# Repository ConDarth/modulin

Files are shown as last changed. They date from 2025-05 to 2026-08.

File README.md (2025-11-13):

# Modulin

This repository holds all data for th modulin I am building. The concept behind this design is to make a fully analog synthesizer using only standard components, with a fun control system based on a violin. This project is mostly based on a design Martin Molin of Wintergatan. An explanation of his design can be found [here](https://www.youtube.com/watch?v=MUdWeBYe3GY). 

My goal in improving this design is to make it more accessible. His design uses 9 or so prebuilt modules meant for modular synthesizers, each of which costs in the range of 70$+ making the instrument quite expensive for a diy build. I took inspiration from the modular synth DIY community to instead try and build the necessary modules from scratch using only much cheaper standard electronics components. The components I am limiting myself to are resistors, capacitors, inductors/transformers, diodes, transistors (both BJT and FET), op amps and linear voltage regulators.

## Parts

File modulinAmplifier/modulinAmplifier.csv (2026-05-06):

Reference | Qty | Value | DNP | Exclude from BOM | Exclude from Board | Footprint | Datasheet
C1,C2,C6 | 3 | 100u |  |  |  | User:C_Radial_Polarized_P3.8mm_CNC
C3,C4 | 2 | 1u |  |  |  | User:C_Axial_P5.00mm_CNC | ~
C5 | 1 | 10u |  |  |  | User:C_Axial_P5.00mm_CNC | ~
C7 | 1 | 33n |  |  |  | User:C_Axial_P5.00mm_CNC | ~
C8 | 1 | 47n |  |  |  | User:C_Axial_P5.00mm_CNC | ~
C9 | 1 | 220u |  |  |  | User:C_Radial_Polarized_P3.8mm_CNC
C10 | 1 | 100n |  |  |  | User:C_Axial_P5.00mm_CNC | ~
D1,D2 | 2 | 1N4148 |  |  |  | User:D_P7.62mm_CNC | https://assets.nexperia.com/documents/data-sheet/1N4148_1N4448.pdf
J1 | 1 | Screw_Terminal_01x04 |  |  |  | User:TerminalBlock_1x4_CNC | ~
J2 | 1 | AudioJack3_SwitchTR |  |  |  | Connector_Audio:Jack_3.5mm_CUI_SJ1-3525N_Horizontal | ~
J3 | 1 | Screw_Terminal_01x02 |  |  |  | User:TerminalBlock_1x2_CNC | ~
R1 | 1 | 1M |  |  |  | User:R_10.16mm_CNC | ~
R2 | 1 | 100 |  |  |  | User:R_10.16mm_CNC | ~
R3 | 1 | 10k |  |  |  | User:R_7.62mm_CNC | ~
R4 | 1 | 10 |  |  |  | User:R_10.16mm_CNC | ~
RV1 | 1 | 100k |  |  |  | User:Potentiometer_PanelMount_CNC | ~
RV2 | 1 | 100k |  |  |  | User:Potentiometer_Trim_CNC | ~
U1 | 1 | TL072 |  |  |  | User:DIP-8_CNC | http://www.ti.com/lit/ds/symlink/tl071.pdf
U2 | 1 | LM386 |  |  |  | User:DIP-8_CNC | http://www.ti.com/lit/ds/symlink/lm386.pdf

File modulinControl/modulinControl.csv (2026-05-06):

Reference | Qty | Value | DNP | Exclude from BOM | Exclude from Board | Footprint | Datasheet
C1,C2 | 2 | 100u |  |  |  | User:C_Radial_Polarized_P3.8mm_CNC | ~
C3,C4 | 2 | 1u |  |  |  | User:C_Axial_P5.00mm_CNC | ~
C5 | 1 | 47n |  |  |  | User:C_Axial_P5.00mm_CNC | ~
D1 | 1 | 1N4148 |  |  |  | User:D_P7.62mm_CNC | https://assets.nexperia.com/documents/data-sheet/1N4148_1N4448.pdf
J1 | 1 | Screw_Terminal_01x05 |  |  |  | User:TerminalBlock_1x5_CNC | ~
J2 | 1 | Screw_Terminal_01x06 |  |  |  | User:TerminalBlock_1x6_CNC | ~
R1,R7 | 2 | 220k |  |  |  | User:R_10.16mm_CNC | ~
R2,R4,R5,R6 | 4 | 100k |  |  |  | User:R_10.16mm_CNC | ~
R3 | 1 | 1k |  |  |  | User:R_10.16mm_CNC | ~
RV1,RV2 | 2 | 100k |  |  |  | User:Potentiometer_Trim_CNC | ~
RV3 | 1 | 10k |  |  |  | User:Potentiometer_Trim_CNC | ~
U1 | 1 | TL074 |  |  |  | User:DIP-14_CNC | http://www.ti.com/lit/ds/symlink/tl071.pdf

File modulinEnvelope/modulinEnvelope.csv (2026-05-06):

Reference | Qty | Value | DNP | Exclude from BOM | Exclude from Board | Footprint | Datasheet
C1 | 1 | 1n |  |  |  | User:C_Rect_P5.00mm_CNC | ~
C2 | 1 | 10n |  |  |  | User:C_Rect_P5.00mm_CNC | ~
C3 | 1 | 4u7 |  |  |  | User:C_Rect_P5.00mm_CNC | ~
D1 | 1 | 1N4148 |  |  |  | User:D_P7.62mm_CNC | https://www.diodes.com/assets/Datasheets/ds30396.pdf
D2,D3,D4 | 3 | 1N4148 |  |  |  | User:D_P10.16mm_CNC | https://www.diodes.com/assets/Datasheets/ds30396.pdf
J1 | 1 | Screw_Terminal_01x06 |  |  |  | User:TerminalBlock_1x6_CNC | ~
Q1,Q2,Q3,Q4,Q5,Q6 | 6 | BC548 |  |  |  | User:TO-92_CNC | https://www.onsemi.com/pub/Collateral/BC550-D.pdf
Q7 | 1 | 2N7000 |  |  |  | User:TO-92_CNC | https://www.vishay.com/docs/70226/70226.pdf
R1 | 1 | 220k |  |  |  | User:R_10.16mm_CNC | ~
R2 | 1 | 820 |  |  |  | User:R_10.16mm_CNC | ~
R3 | 1 | 1k 1% |  |  |  | User:R_7.62mm_CNC | ~
R4 | 1 | 1k 1% |  |  |  | User:R_2.54mm_CNC | ~
R5,R7,R8 | 3 | 22k |  |  |  | User:R_10.16mm_CNC | ~
R6,R9,R10 | 3 | 10k |  |  |  | User:R_10.16mm_CNC | ~
R11 | 1 | 680k |  |  |  | User:R_7.62mm_CNC | ~
R12 | 1 | 680k |  |  |  | User:R_10.16mm_CNC | ~
R13,R15,R17 | 3 | 47k |  |  |  | User:R_7.62mm_CNC | ~
R14 | 1 | 220k |  |  |  | User:R_7.62mm_CNC | ~
R16,R23,R24 | 3 | 100k |  |  |  | User:R_7.62mm_CNC | ~
R18 | 1 | 1M |  |  |  | User:R_7.62mm_CNC | ~
R19,R20,R22 | 3 | 100 |  |  |  | User:R_10.16mm_CNC | ~
R21 | 1 | 47k |  |  |  | User:R_10.16mm_CNC | ~
RV1 | 1 | 1k |  |  |  | User:Potentiometer_Trim_CNC | ~
RV2 | 1 | 100k |  |  |  | User:Potentiometer_Trim_CNC | ~
RV3,RV4,RV6 | 3 | A1M |  |  |  | User:Potentiometer_PanelMount_CNC | ~
RV5 | 1 | B100k |  |  |  | User:Potentiometer_PanelMount_CNC | ~
U1 | 1 | TL074 |  |  |  | User:DIP-14_CNC | http://www.ti.com/lit/ds/symlink/tl071.pdf
U2 | 1 | NA555P |  |  |  | User:DIP-8_CNC | http://www.ti.com/lit/ds/symlink/ne555.pdf

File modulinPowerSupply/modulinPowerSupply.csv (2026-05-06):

Reference | Qty | Value | DNP | Exclude from BOM | Exclude from Board | Footprint | Datasheet
C1,C2,C3,C4,C5,C6 | 6 | 4700uF |  |  |  | User:C_Radial_Polarized_P7.50mm_CNC
C7,C8,C9,C10 | 4 | 1uF |  |  |  | User:C_Rect_P5.00mm_CNC
D1,D2,D3,D4 | 4 | 1N4001 |  |  |  | User:D_P10.16mm_CNC | http://www.vishay.com/docs/88503/1n4001.pdf
J1 | 1 | Screw_Terminal_01x02 |  |  |  | User:TerminalBlock_1x2_CNC | ~
J2 | 1 | Screw_Terminal_01x03 |  |  |  | User:TerminalBlock_1x3_CNC | ~
U1 | 1 | LM7812_TO220 |  |  |  | User:TO-220_CNC | https://www.onsemi.cn/PowerSolutions/document/MC7800-D.PDF
U2 | 1 | LM7912_TO220 |  |  |  | User:TO-220_CNC | hhttps://www.onsemi.com/pub/Collateral/MC7900-D.PDF

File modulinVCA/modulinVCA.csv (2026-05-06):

Reference | Qty | Value | DNP | Exclude from BOM | Exclude from Board | Footprint | Datasheet
C1,C2,C3,C4 | 4 | 10u |  |  |  | User:C_Axial_P5.00mm_CNC | ~
J1 | 1 | Screw_Terminal_01x08 |  |  |  | User:TerminalBlock_1x8_CNC | ~
Q1,Q2,Q3,Q4,Q5,Q6 | 6 | BC548 |  |  |  | User:TO-92_CNC | https://www.onsemi.com/pub/Collateral/BC550-D.pdf
R1,R15 | 2 | 220k |  |  |  | User:R_2.54mm_CNC | ~
R2 | 1 | 820 |  |  |  | User:R_2.54mm_CNC | ~
R3,R20 | 2 | 1k 1% |  |  |  | User:R_7.62mm_CNC | ~
R4,R19 | 2 | 1k 1% |  |  |  | User:R_2.54mm_CNC | ~
R5,R17 | 2 | 22k |  |  |  | User:R_10.16mm_CNC | ~
R6,R18 | 2 | 10k |  |  |  | User:R_2.54mm_CNC_Alt | ~
R7,R13 | 2 | 22k |  |  |  | User:R_5.08mm_CNC | ~
R8,R14 | 2 | 22k |  |  |  | User:R_2.54mm_CNC | ~
R9 | 1 | 10k |  |  |  | User:R_10.16mm_CNC | ~
R10,R22 | 2 | 10k |  |  |  | User:R_2.54mm_CNC | ~
R11,R24 | 2 | 680k |  |  |  | User:R_2.54mm_CNC | ~
R12,R23 | 2 | 680k |  |  |  | User:R_5.08mm_CNC | ~
R16 | 1 | 820 |  |  |  | User:R_2.54mm_CNC_Alt | ~
R21 | 1 | 10k |  |  |  | User:R_7.62mm_CNC | ~
R25,R26 | 2 | 100k |  |  |  | User:R_10.16mm_CNC | ~
RV1,RV6 | 2 | 1k |  |  |  | User:Potentiometer_Trim_CNC | ~
RV2,RV5 | 2 | 100k |  |  |  | User:Potentiometer_Trim_CNC | ~
RV3 | 1 | B100k |  |  |  | User:Potentiometer_PanelMount_CNC | ~
RV4 | 1 | B1M |  |  |  | User:Potentiometer_PanelMount_CNC | ~
U1 | 1 | TL074 |  |  |  | User:DIP-14_CNC | http://www.ti.com/lit/ds/symlink/tl071.pdf

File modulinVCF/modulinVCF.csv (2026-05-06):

Reference | Qty | Value | DNP | Exclude from BOM | Exclude from Board | Footprint | Datasheet
C1,C2,C12 | 3 | 10u |  |  |  | User:C_Rect_P5.00mm_CNC | ~
C3,C4,C13,C14,C15,C16,C17 | 7 | 10u |  |  |  | User:C_Axial_P5.00mm_CNC | ~
C5 | 1 | 100p |  |  |  | User:C_Axial_P5.00mm_CNC | ~
C6,C18 | 2 | 220n |  |  |  | User:C_Axial_P5.00mm_CNC | ~
C7,C8,C9,C10 | 4 | 47n |  |  |  | User:C_Axial_P5.00mm_CNC | ~
C11 | 1 | 220u |  |  |  | Capacitor_THT:CP_Radial_D8.0mm_P3.80mm | ~
J1 | 1 | Screw_Terminal_01x07 |  |  |  | User:TerminalBlock_1x7_CNC | ~
Q1,Q2,Q3,Q4,Q5,Q6,Q7,Q8,Q9,Q10,Q11,Q12 | 12 | BC548 |  |  |  | User:TO-92_CNC | https://www.onsemi.com/pub/Collateral/BC550-D.pdf
R1,R2,R3,R19,R27 | 5 | 100k |  |  |  | User:R_10.16mm_CNC | ~
R4 | 1 | 2k |  |  |  | User:R_2.54mm_CNC | ~
R5,R9,R10 | 3 | 150 |  |  |  | User:R_7.62mm_CNC | ~
R6 | 1 | 47 |  |  |  | User:R_5.08mm_CNC | ~
R7 | 1 | 1M |  |  |  | User:R_10.16mm_CNC | ~
R8 | 1 | 10k |  |  |  | User:R_7.62mm_CNC | ~
R11 | 1 | 330 |  |  |  | User:R_2.54mm_CNC | ~
R12 | 1 | 470 |  |  |  | User:R_2.54mm_CNC_Alt | ~
R13 | 1 | 150 |  |  |  | User:R_2.54mm_CNC | ~
R14 | 1 | 330 |  |  |  | User:R_7.62mm_CNC | ~
R15 | 1 | 1k |  |  |  | User:R_7.62mm_CNC | ~
R16 | 1 | 220 |  |  |  | User:R_10.16mm_CNC | ~
R17 | 1 | 22k |  |  |  | User:R_2.54mm_CNC | ~
R18 | 1 | 10k |  |  |  | User:R_5.08mm_CNC | ~
R20,R21 | 2 | 10k 1% |  |  |  | User:R_10.16mm_CNC | ~
R22 | 1 | 1M 1% |  |  |  | User:R_2.54mm_CNC | ~
R23 | 1 | 1M 1% |  |  |  | User:R_7.62mm_CNC | ~
R24 | 1 | 220k |  |  |  | User:R_10.16mm_CNC | ~
R25 | 1 | 47k |  |  |  | User:R_10.16mm_CNC | ~
R26 | 1 | 10k |  |  |  | User:R_10.16mm_CNC | ~
R28 | 1 | 5.1k |  |  |  | User:R_2.54mm_CNC | ~
RV1,RV2 | 2 | B100k |  |  |  | User:Potentiometer_PanelMount_CNC | ~
RV3 | 1 | C100k |  |  |  | User:Potentiometer_PanelMount_CNC | ~
RV4 | 1 | 1k |  |  |  | User:Potentiometer_Trim_CNC | ~
RV5 | 1 | 10k |  |  |  | User:Potentiometer_Trim_CNC | ~
RV6 | 1 | 500k |  |  |  | User:Potentiometer_Trim_CNC | ~
U1,U3 | 2 | TL074 |  |  |  | User:DIP-14_CNC | http://www.ti.com/lit/ds/symlink/tl071.pdf
U2 | 1 | LM7805 |  |  |  | User:TO-220_CNC | https://www.onsemi.cn/PowerSolutions/document/MC7800-D.PDF
U4 | 1 | TL072 |  |  |  | User:DIP-8_CNC | http://www.ti.com/lit/ds/symlink/tl071.pdf

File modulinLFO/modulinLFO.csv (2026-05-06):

Reference | Qty | Value | DNP | Exclude from BOM | Exclude from Board | Footprint | Datasheet
C1 | 1 | 100p |  |  |  | User:C_Axial_P5.00mm_CNC | ~
C2 | 1 | 10n |  |  |  | User:C_Rect_P5.00mm_CNC | ~
C3 | 1 | 20p |  |  |  | User:C_Axial_P5.00mm_CNC | ~
C4,C5 | 2 | 220n |  |  |  | User:C_Axial_P5.00mm_CNC | ~
C6,C7,C8,C9,C10,C11,C12,C13,C14,C15,C16,C17,C20,C21 | 14 | 100n |  |  |  | User:C_Axial_P5.00mm_CNC | ~
C18 | 1 | 100p |  |  |  | User:C_Rect_P5.00mm_CNC | ~
C19 | 1 | 47p |  |  |  | User:C_Rect_P5.00mm_CNC | ~
C22,C23 | 2 | 100u |  |  |  | User:C_Radial_Polarized_P2.5mm_CNC | ~
D1 | 1 | 5V1 |  |  |  | User:D_P2.54mm_CNC | ~
D2 | 1 | 5V1 |  |  |  | User:D_P5.08mm_CNC | ~
D3,D4 | 2 | 1N4148 |  |  |  | User:D_P7.62mm_CNC | https://assets.nexperia.com/documents/data-sheet/1N4148_1N4448.pdf
J1 | 1 | Screw_Terminal_01x05 |  |  |  | User:TerminalBlock_1x5_CNC | ~
Q1,Q2,Q4,Q5,Q6,Q7,Q8 | 7 | BC548 |  |  |  | User:TO-92_CNC | https://www.onsemi.com/pub/Collateral/BC550-D.pdf
Q3 | 1 | 2N7000 |  |  |  | User:TO-92_CNC | https://www.vishay.com/docs/70226/70226.pdf
R1 | 1 | 2M2 |  |  |  | User:R_10.16mm_CNC | ~
R2,R42 | 2 | 220k |  |  |  | User:R_10.16mm_CNC | ~
R3,R46 | 2 | 1k 1% |  |  |  | User:R_7.62mm_CNC | ~
R4 | 1 | 220k |  |  |  | User:R_2.54mm_CNC | ~
R5 | 1 | 22k |  |  |  | User:R_2.54mm_CNC | ~
R6 | 1 | 47 |  |  |  | User:R_5.08mm_CNC | ~
R7 | 1 | 1M |  |  |  | User:R_10.16mm_CNC | ~
R8,R9,R25,R45,R47,R48 | 6 | 10k |  |  |  | User:R_10.16mm_CNC | ~
R10,R44,R51 | 3 | 22k |  |  |  | User:R_10.16mm_CNC | ~
R11 | 1 | 100k |  |  |  | User:R_7.62mm_CNC | ~
R12 | 1 | 51k |  |  |  | User:R_5.08mm_CNC | ~
R13,R16,R23 | 3 | 100k 1% |  |  |  | User:R_10.16mm_CNC | ~
R14,R17,R24,R28 | 4 | 100k 1% |  |  |  | User:R_2.54mm_CNC | ~
R15 | 1 | 1k |  |  |  | User:R_7.62mm_CNC | ~
R18,R31 | 2 | 100k |  |  |  | User:R_2.54mm_CNC | ~
R19,R41 | 2 | 100k |  |  |  | User:R_2.54mm_CNC_Alt | ~
R20 | 1 | 22k |  |  |  | User:R_7.62mm_CNC | ~
R21 | 1 | 47k |  |  |  | User:R_7.62mm_CNC | ~
R22,R30 | 2 | 47k |  |  |  | User:R_10.16mm_CNC | ~
R26,R32 | 2 | 100k |  |  |  | User:R_10.16mm_CNC | ~
R27 | 1 | 33k |  |  |  | User:R_2.54mm_CNC_Alt | ~
R29 | 1 | 100k 1% |  |  |  | User:R_7.62mm_CNC | ~
R33,R36 | 2 | 2k2 |  |  |  | User:R_10.16mm_CNC | ~
R34,R35 | 2 | 1k 1% |  |  |  | User:R_10.16mm_CNC | ~
R37 | 1 | 390 |  |  |  | User:R_5.08mm_CNC | ~
R38 | 1 | 18k |  |  |  | User:R_10.16mm_CNC | ~
R39 | 1 | 10k 1% |  |  |  | User:R_10.16mm_CNC | ~
R40 | 1 | 10k 1% |  |  |  | User:R_2.54mm_CNC_Alt | ~
R43 | 1 | 820 |  |  |  | User:R_10.16mm_CNC | ~
R49 | 1 | 680k |  |  |  | User:R_10.16mm_CNC | ~
R50 | 1 | 680k |  |  |  | User:R_7.62mm_CNC | ~
RV1,RV2,RV8,RV16 | 4 | B100k |  |  |  | User:Potentiometer_PanelMount_CNC | ~
RV3 | 1 | A1M |  |  |  | User:Potentiometer_PanelMount_CNC | ~
RV4,RV15 | 2 | 1k |  |  |  | User:Potentiometer_Trim_CNC | ~
RV5,RV6,RV9,RV10,RV11,RV13,RV14 | 7 | 100k |  |  |  | User:Potentiometer_Trim_CNC | ~
RV12 | 1 | 50k |  |  |  | User:Potentiometer_Trim_CNC | ~
SW1 | 1 | SW_SPDT |  |  |  | User:SW_Slide_SPDT_H6.00mm_CNC | ~
SW2 | 1 | SW_1x4 |  |  |  | User:SW_Slide_SP4T_H6.00mm_CNC | ~
U1,U3,U4 | 3 | TL074 |  |  |  | User:DIP-14_CNC | http://www.ti.com/lit/ds/symlink/tl071.pdf
U2 | 1 | LM7805 |  |  |  | User:TO-220_CNC | https://www.onsemi.cn/PowerSolutions/document/MC7800-D.PDF
U5,U6,U7,U8 | 4 | TL072 |  |  |  | User:DIP-8_CNC | http://www.ti.com/lit/ds/symlink/tl071.pdf

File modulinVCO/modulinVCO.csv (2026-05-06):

Reference | Qty | Value | DNP | Exclude from BOM | Exclude from Board | Footprint | Datasheet
C1 | 1 | 100p |  |  |  | User:C_Axial_P5.00mm_CNC | ~
C2 | 1 | 10n |  |  |  | User:C_Rect_P5.00mm_CNC | ~
C3 | 1 | 20p |  |  |  | User:C_Axial_P5.00mm_CNC | ~
C4,C5 | 2 | 220n |  |  |  | User:C_Axial_P5.00mm_CNC | ~
C6,C7,C8,C9,C12,C13,C14,C15,C16,C17,C20,C21,C22,C23 | 14 | 100n |  |  |  | User:C_Axial_P5.00mm_CNC | ~
C10,C11 | 2 | 100n |  |  |  | User:C_Radial_Polarized_P3.8mm_CNC | ~
C18 | 1 | 100p |  |  |  | User:C_Rect_P5.00mm_CNC | ~
C19 | 1 | 47p |  |  |  | User:C_Rect_P5.00mm_CNC | ~
D1 | 1 | 5V1 |  |  |  | User:D_P2.54mm_CNC | ~
D2 | 1 | 5V1 |  |  |  | User:D_P5.08mm_CNC | ~
D3,D4 | 2 | 1N4148 |  |  |  | User:D_P7.62mm_CNC | https://assets.nexperia.com/documents/data-sheet/1N4148_1N4448.pdf
J1 | 1 | Conn_01x06_Pin |  |  |  | User:TerminalBlock_1x6_CNC | ~
Q1,Q2,Q4,Q5 | 4 | BC548 |  |  |  | User:TO-92_CNC | https://www.onsemi.com/pub/Collateral/BC550-D.pdf
Q3 | 1 | 2N7000 |  |  |  | User:TO-92_CNC | https://www.vishay.com/docs/70226/70226.pdf
R1 | 1 | 2M2 |  |  |  | User:R_10.16mm_CNC | ~
R2,R42,R43,R44,R45 | 5 | 220k |  |  |  | User:R_10.16mm_CNC | ~
R3,R18 | 2 | 100k |  |  |  | User:R_2.54mm_CNC | ~
R4 | 1 | 220k |  |  |  | User:R_2.54mm_CNC | ~
R5,R47 | 2 | 22k |  |  |  | User:R_2.54mm_CNC | ~
R6 | 1 | 47 |  |  |  | User:R_5.08mm_CNC | ~
R7 | 1 | 1M |  |  |  | User:R_10.16mm_CNC | ~
R8,R9,R25 | 3 | 10k |  |  |  | User:R_10.16mm_CNC | ~
R10 | 1 | 22k |  |  |  | User:R_10.16mm_CNC | ~
R11 | 1 | 100k |  |  |  | User:R_7.62mm_CNC | ~
R12 | 1 | 51k |  |  |  | User:R_5.08mm_CNC | ~
R13,R16,R23 | 3 | 100k 1% |  |  |  | User:R_10.16mm_CNC | ~
R14,R17,R24,R28,R31 | 5 | 100k 1% |  |  |  | User:R_2.54mm_CNC | ~
R15 | 1 | 1k |  |  |  | User:R_7.62mm_CNC | ~
R19,R41 | 2 | 100k |  |  |  | User:R_2.54mm_CNC_Alt | ~
R20 | 1 | 100k 1% |  |  |  | User:R_5.08mm_CNC | ~
R21 | 1 | 47k |  |  |  | User:R_7.62mm_CNC | ~
R22,R30 | 2 | 47k |  |  |  | User:R_10.16mm_CNC | ~
R26,R32 | 2 | 100k |  |  |  | User:R_10.16mm_CNC | ~
R27 | 1 | 33k |  |  |  | User:R_2.54mm_CNC_Alt | ~
R29 | 1 | 100k 1% |  |  |  | User:R_7.62mm_CNC | ~
R33,R36 | 2 | 2k2 |  |  |  | User:R_10.16mm_CNC | ~
R34,R35 | 2 | 1k 1% |  |  |  | User:R_10.16mm_CNC | ~
R37 | 1 | 390 |  |  |  | User:R_5.08mm_CNC | ~
R38 | 1 | 18k |  |  |  | User:R_10.16mm_CNC | ~
R39 | 1 | 10k 1% |  |  |  | User:R_10.16mm_CNC | ~
R40 | 1 | 10k 1% |  |  |  | User:R_2.54mm_CNC_Alt | ~
R46 | 1 | 51k |  |  |  | User:R_2.54mm_CNC | ~
R48 | 1 | 22k |  |  |  | User:R_5.08mm_CNC_Alt | ~
RV1,RV2,RV7,RV8,RV14,RV15,RV16,RV17,RV18 | 9 | B100k |  |  |  | User:Potentiometer_PanelMount_CNC | ~
RV3 | 1 | A1M |  |  |  | User:Potentiometer_PanelMount_CNC | ~
RV4 | 1 | 1k |  |  |  | User:Potentiometer_Trim_CNC | ~
RV5,RV6,RV9,RV10,RV11,RV13 | 6 | 100k |  |  |  | User:Potentiometer_Trim_CNC | ~
RV12 | 1 | 50k |  |  |  | User:Potentiometer_Trim_CNC | ~
SW1 | 1 | SW_SPDT |  |  |  | User:SW_Slide_SPDT_H6.00mm_CNC | ~
U1,U3,U4 | 3 | TL074 |  |  |  | User:DIP-14_CNC | http://www.ti.com/lit/ds/symlink/tl071.pdf
U2 | 1 | LM7805 |  |  |  | User:TO-220_CNC | https://www.onsemi.cn/PowerSolutions/document/MC7800-D.PDF
U5,U6,U7,U8 | 4 | TL072 |  |  |  | User:DIP-8_CNC | http://www.ti.com/lit/ds/symlink/tl071.pdf

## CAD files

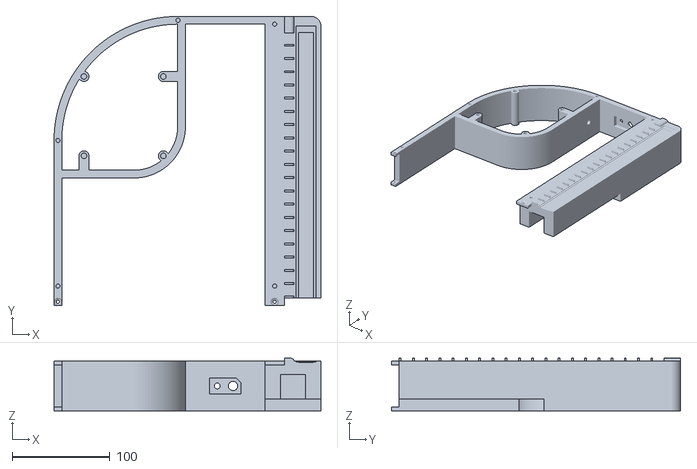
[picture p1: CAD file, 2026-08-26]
CAD/MainBodyRight.stl
273.4 x 296.1 x 53.8

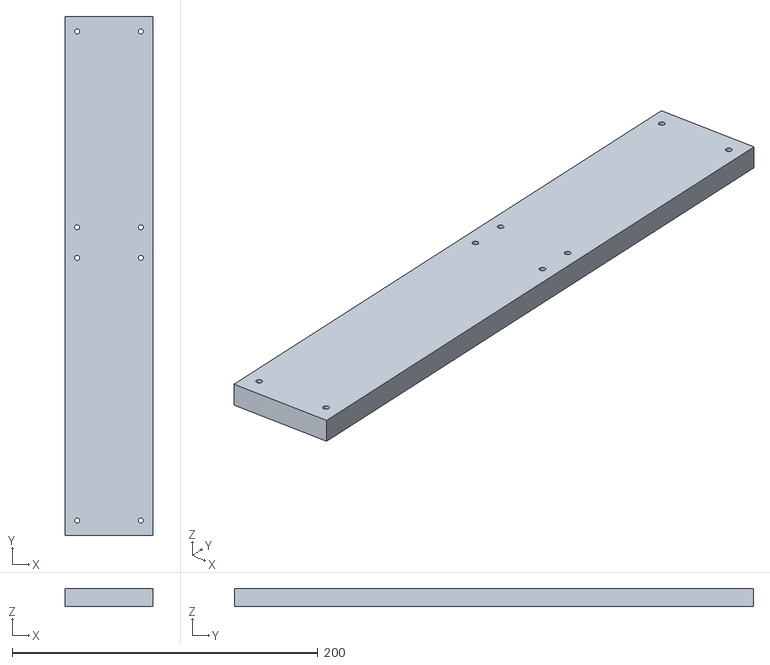
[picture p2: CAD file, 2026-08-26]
CAD/MainBodyCap.stl
57.5 x 339.6 x 11.8

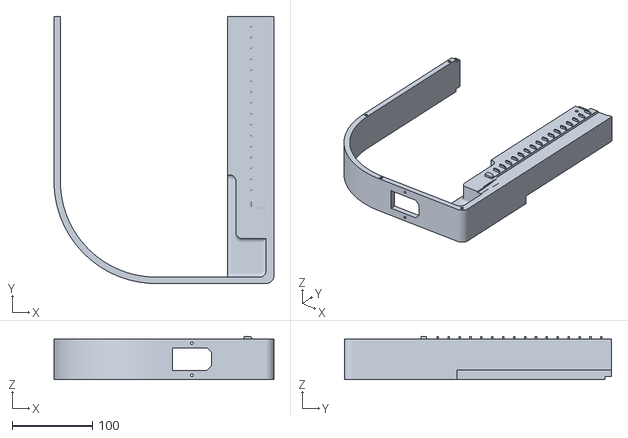
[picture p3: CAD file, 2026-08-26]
CAD/MainBodyLeft.stl
273.4 x 331.9 x 53.8

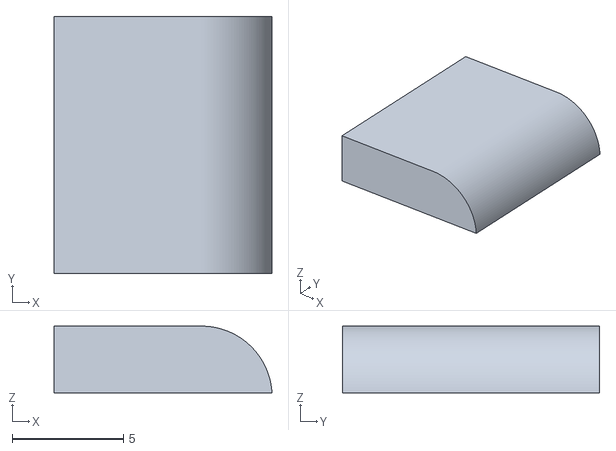
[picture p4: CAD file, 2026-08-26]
CAD/Key6ASharp.stl
9.80 x 11.6 x 3.00

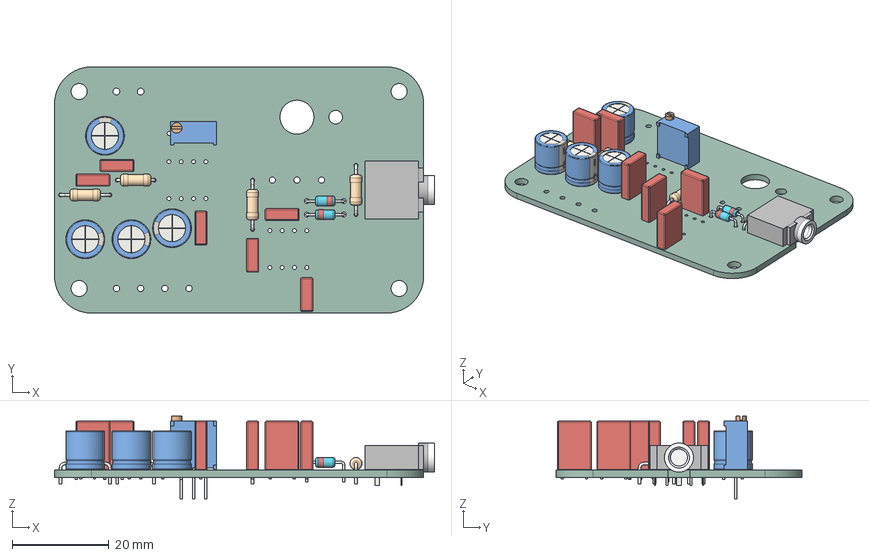
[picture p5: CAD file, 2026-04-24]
modulinAmplifier/modulinAmplifier.step
78.4 x 50.8 x 17.1 mm
C_Rect_L7.0mm_W2.5mm_P5.00mm x 6
D_DO-35_SOD27_P7.62mm_Horizontal x 2
R_Axial_DIN0207_L6.3mm_D2.5mm_P10.16mm_Horizontal x 3
CP_Radial_D8.0mm_P3.80mm x 4
R_Axial_DIN0207_L6.3mm_D2.5mm_P7.62mm_Horizontal
Potentiometer_Bourns_3296W_Vertical
Jack_3.5mm_CUI_SJ1-3525N_Horizontal
modulinAmplifier_PCB

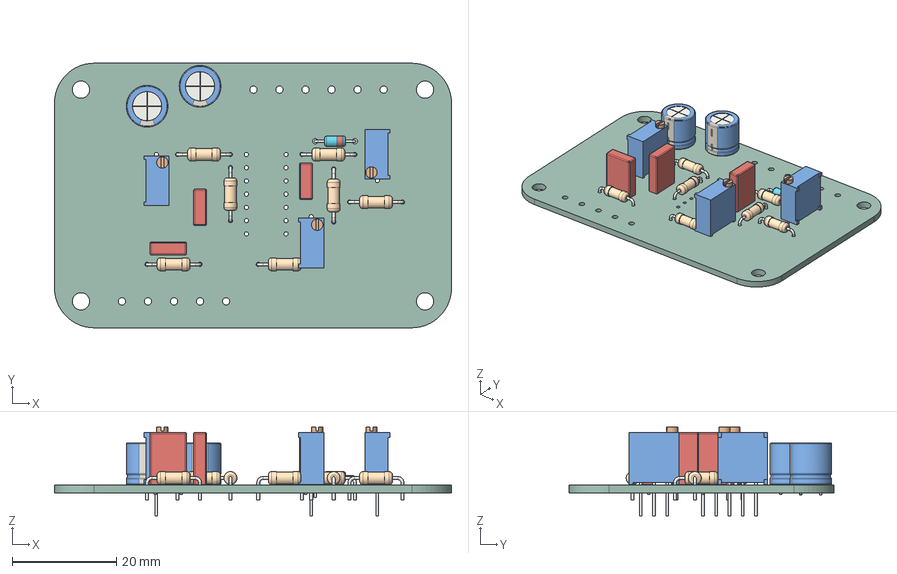
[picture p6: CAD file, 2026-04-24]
modulinControl/modulinControl.step
76.2 x 50.8 x 17.1 mm
R_Axial_DIN0207_L6.3mm_D2.5mm_P10.16mm_Horizontal x 7
C_Rect_L7.0mm_W2.5mm_P5.00mm x 3
D_DO-35_SOD27_P7.62mm_Horizontal
Potentiometer_Bourns_3296W_Vertical x 3
CP_Radial_D8.0mm_P3.80mm x 2
modulinControl_PCB

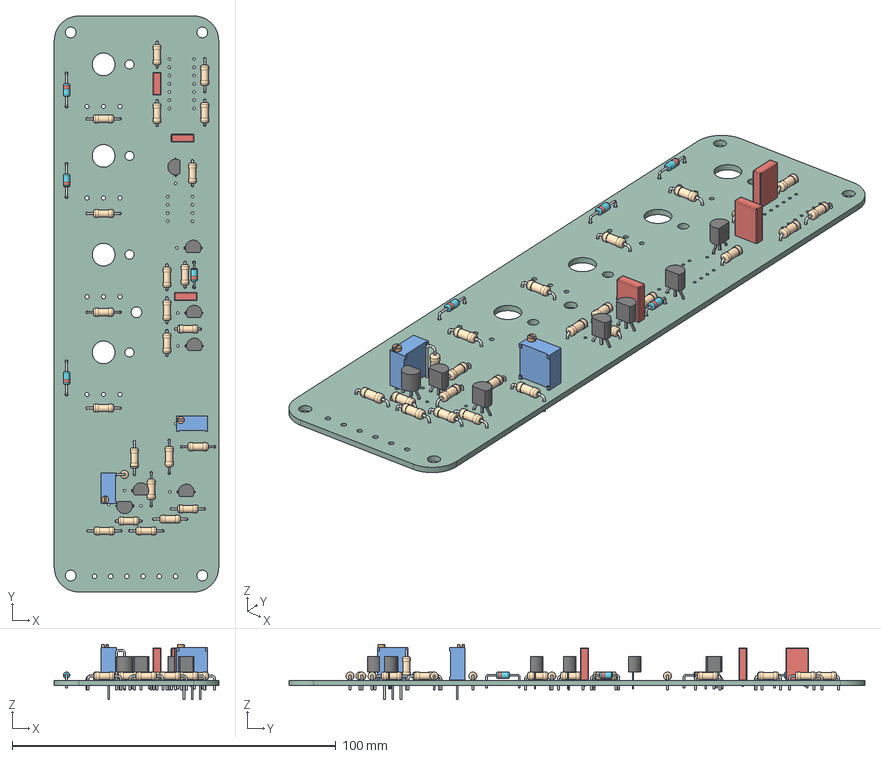
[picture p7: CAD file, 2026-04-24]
modulinEnvelope/modulinEnvelope.step
50.8 x 177.8 x 17.1 mm
D_DO-35_SOD27_P7.62mm_Horizontal
D_DO-35_SOD27_P10.16mm_Horizontal x 3
R_Axial_DIN0207_L6.3mm_D2.5mm_P7.62mm_Horizontal x 10
R_Axial_DIN0207_L6.3mm_D2.5mm_P2.54mm_Vertical
R_Axial_DIN0207_L6.3mm_D2.5mm_P10.16mm_Horizontal x 13
Potentiometer_Bourns_3296W_Vertical x 2
TO-92_Inline_Wide x 7
C_Rect_L7.0mm_W2.5mm_P5.00mm x 3
modulinEnvelope_PCB

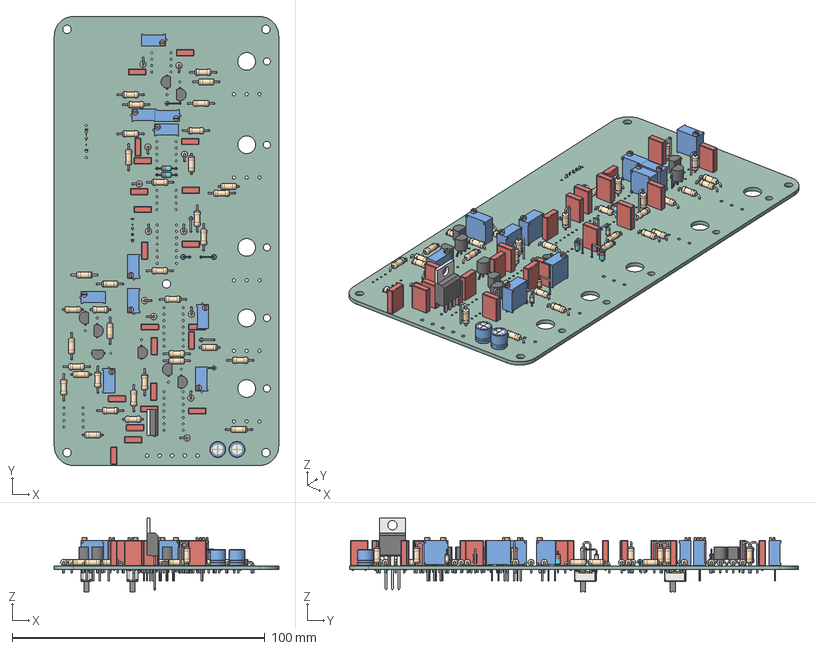
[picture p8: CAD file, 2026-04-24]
modulinLFO/modulinLFO.step
88.9 x 177.8 x 29.2 mm
C_Rect_L7.0mm_W2.5mm_P5.00mm x 21
R_Axial_DIN0207_L6.3mm_D2.5mm_P10.16mm_Horizontal x 28
R_Axial_DIN0207_L6.3mm_D2.5mm_P2.54mm_Vertical x 12
TO-92_Inline_Wide x 8
D_DO-35_SOD27_P5.08mm_Vertical_KathodeUp
Potentiometer_Bourns_3296W_Vertical x 10
TO-220-3_Vertical
R_Axial_DIN0207_L6.3mm_D2.5mm_P7.62mm_Horizontal x 8
D_DO-35_SOD27_P7.62mm_Horizontal x 2
CP_Radial_D6.3mm_P2.50mm x 2
R_Axial_DIN0204_L3.6mm_D1.6mm_P5.08mm_Vertical x 4
D_DO-35_SOD27_P2.54mm_Vertical_KathodeUp
SW_Slide_SPDT_Straight_CK_OS102011MS2Q x 2
modulinLFO_PCB

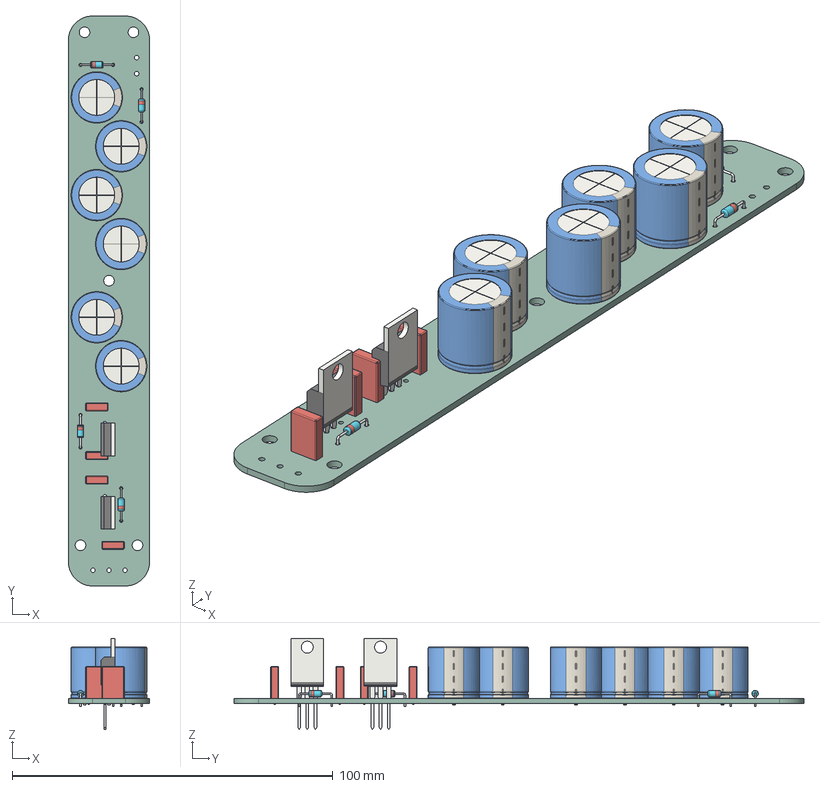
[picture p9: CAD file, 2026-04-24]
modulinPowerSupply/modulinPowerSupply.step
25.4 x 177.8 x 28.5 mm
CP_Radial_D16.0mm_P7.50mm x 6
D_DO-35_SOD27_P10.16mm_Horizontal x 4
C_Rect_L7.0mm_W2.5mm_P5.00mm x 4
TO-220-3_Vertical x 2
modulinPowerSupply_PCB

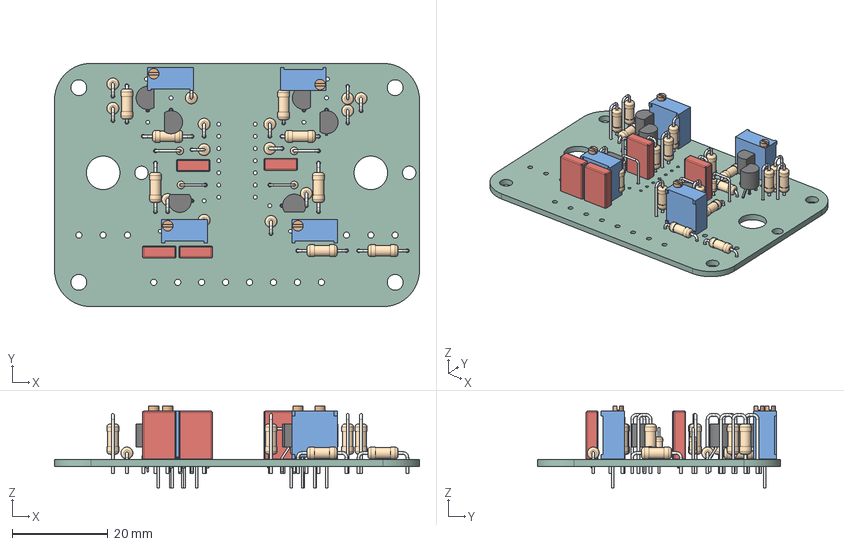
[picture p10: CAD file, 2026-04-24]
modulinVCA/modulinVCA.step
76.2 x 50.8 x 17.1 mm
R_Axial_DIN0207_L6.3mm_D2.5mm_P10.16mm_Horizontal x 5
Potentiometer_Bourns_3296W_Vertical x 4
R_Axial_DIN0207_L6.3mm_D2.5mm_P2.54mm_Vertical x 14
TO-92_Inline_Wide x 6
C_Rect_L7.0mm_W2.5mm_P5.00mm x 4
R_Axial_DIN0207_L6.3mm_D2.5mm_P7.62mm_Horizontal x 3
R_Axial_DIN0204_L3.6mm_D1.6mm_P5.08mm_Vertical x 4
modulinVCA_PCB

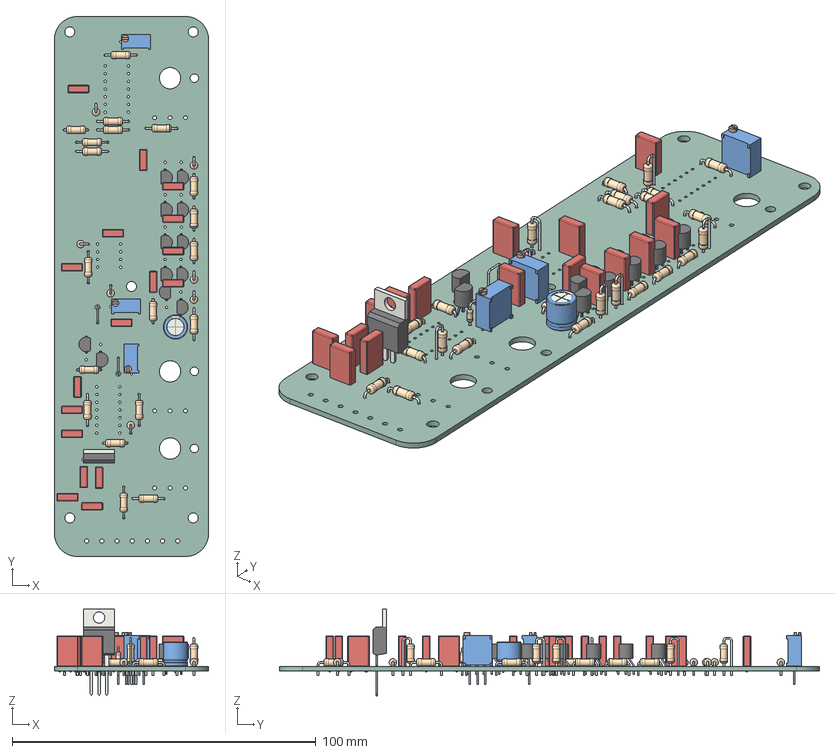
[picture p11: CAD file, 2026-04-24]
modulinVCF/modulinVCF.step
50.8 x 177.8 x 28.5 mm
Potentiometer_Bourns_3296W_Vertical x 3
R_Axial_DIN0207_L6.3mm_D2.5mm_P7.62mm_Horizontal x 7
TO-92_Inline_Wide x 12
R_Axial_DIN0207_L6.3mm_D2.5mm_P10.16mm_Horizontal x 12
R_Axial_DIN0204_L3.6mm_D1.6mm_P5.08mm_Vertical x 2
C_Rect_L7.0mm_W2.5mm_P5.00mm x 17
R_Axial_DIN0207_L6.3mm_D2.5mm_P2.54mm_Vertical x 7
TO-220-3_Vertical
CP_Radial_D8.0mm_P3.80mm
modulinVCF_PCB

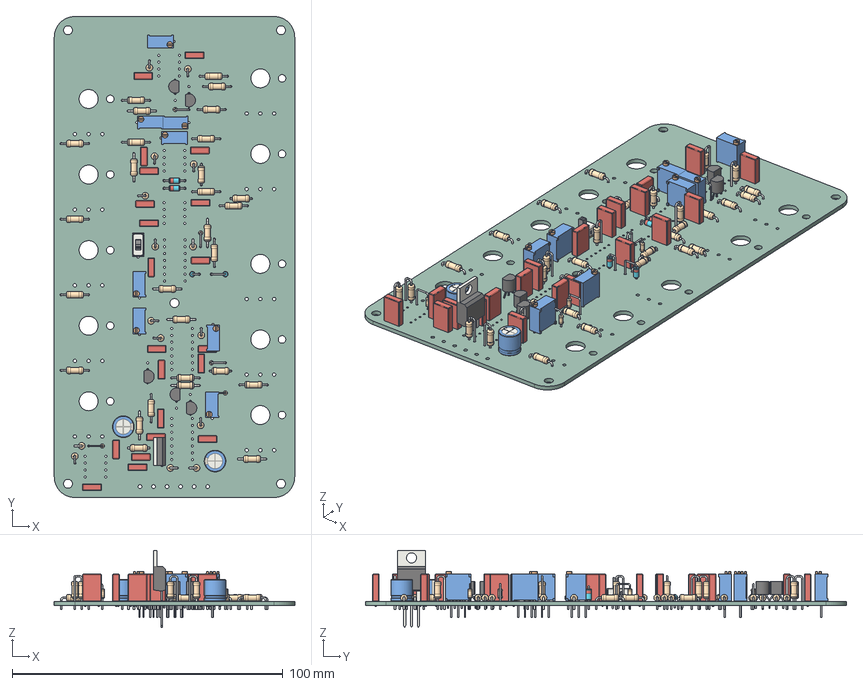
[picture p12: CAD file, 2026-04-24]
modulinVCO/modulinVCO.step
88.9 x 177.8 x 28.5 mm
C_Rect_L7.0mm_W2.5mm_P5.00mm x 21
R_Axial_DIN0207_L6.3mm_D2.5mm_P10.16mm_Horizontal x 24
R_Axial_DIN0204_L3.6mm_D1.6mm_P5.08mm_Vertical x 5
R_Axial_DIN0207_L6.3mm_D2.5mm_P2.54mm_Vertical x 15
D_DO-35_SOD27_P5.08mm_Vertical_KathodeUp
Potentiometer_Bourns_3296W_Vertical x 8
TO-92_Inline_Wide x 5
TO-220-3_Vertical
CP_Radial_D8.0mm_P3.80mm x 2
R_Axial_DIN0207_L6.3mm_D2.5mm_P7.62mm_Horizontal x 4
D_DO-35_SOD27_P7.62mm_Horizontal x 2
SW_Slide_SPDT_Straight_CK_OS102011MS2Q
D_DO-35_SOD27_P2.54mm_Vertical_KathodeUp
modulinVCO_PCB

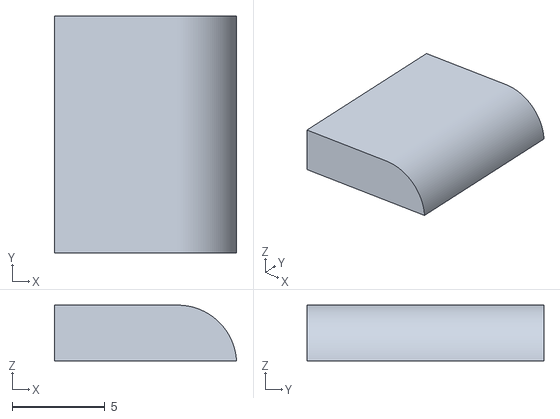
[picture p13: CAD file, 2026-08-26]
CAD/Key3C.stl
9.80 x 12.8 x 3.00

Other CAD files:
CAD/Key5GSharp.stl
CAD/Key4E.stl
CAD/Key5G.stl
CAD/Key4D.stl
CAD/Key3E.stl
CAD/Key3CSharp.stl
CAD/Key3D.stl
CAD/Key3DSharp.stl
CAD/Key3F.stl
CAD/Key3FSharp.stl
CAD/Key3G.stl
CAD/Key3GSharp.stl
CAD/Key4A.stl
CAD/Key4ASharp.stl
CAD/Key4B.stl
CAD/Key4C.stl
CAD/Key4CSharp.stl
CAD/Key4DSharp.stl
CAD/Key4F.stl
CAD/Key4FSharp.stl
CAD/Key4G.stl
CAD/Key4GSharp.stl
CAD/Key5A.stl
CAD/Key5ASharp.stl
CAD/Key5B.stl
CAD/Key5C.stl
CAD/Key5CSharp.stl
CAD/Key5D.stl
CAD/Key5DSharp.stl
CAD/Key5E.stl
CAD/Key5F.stl
CAD/Key5FSharp.stl
CAD/Key6A.stl
CAD/Key6B.stl
CAD/Key6C.stl

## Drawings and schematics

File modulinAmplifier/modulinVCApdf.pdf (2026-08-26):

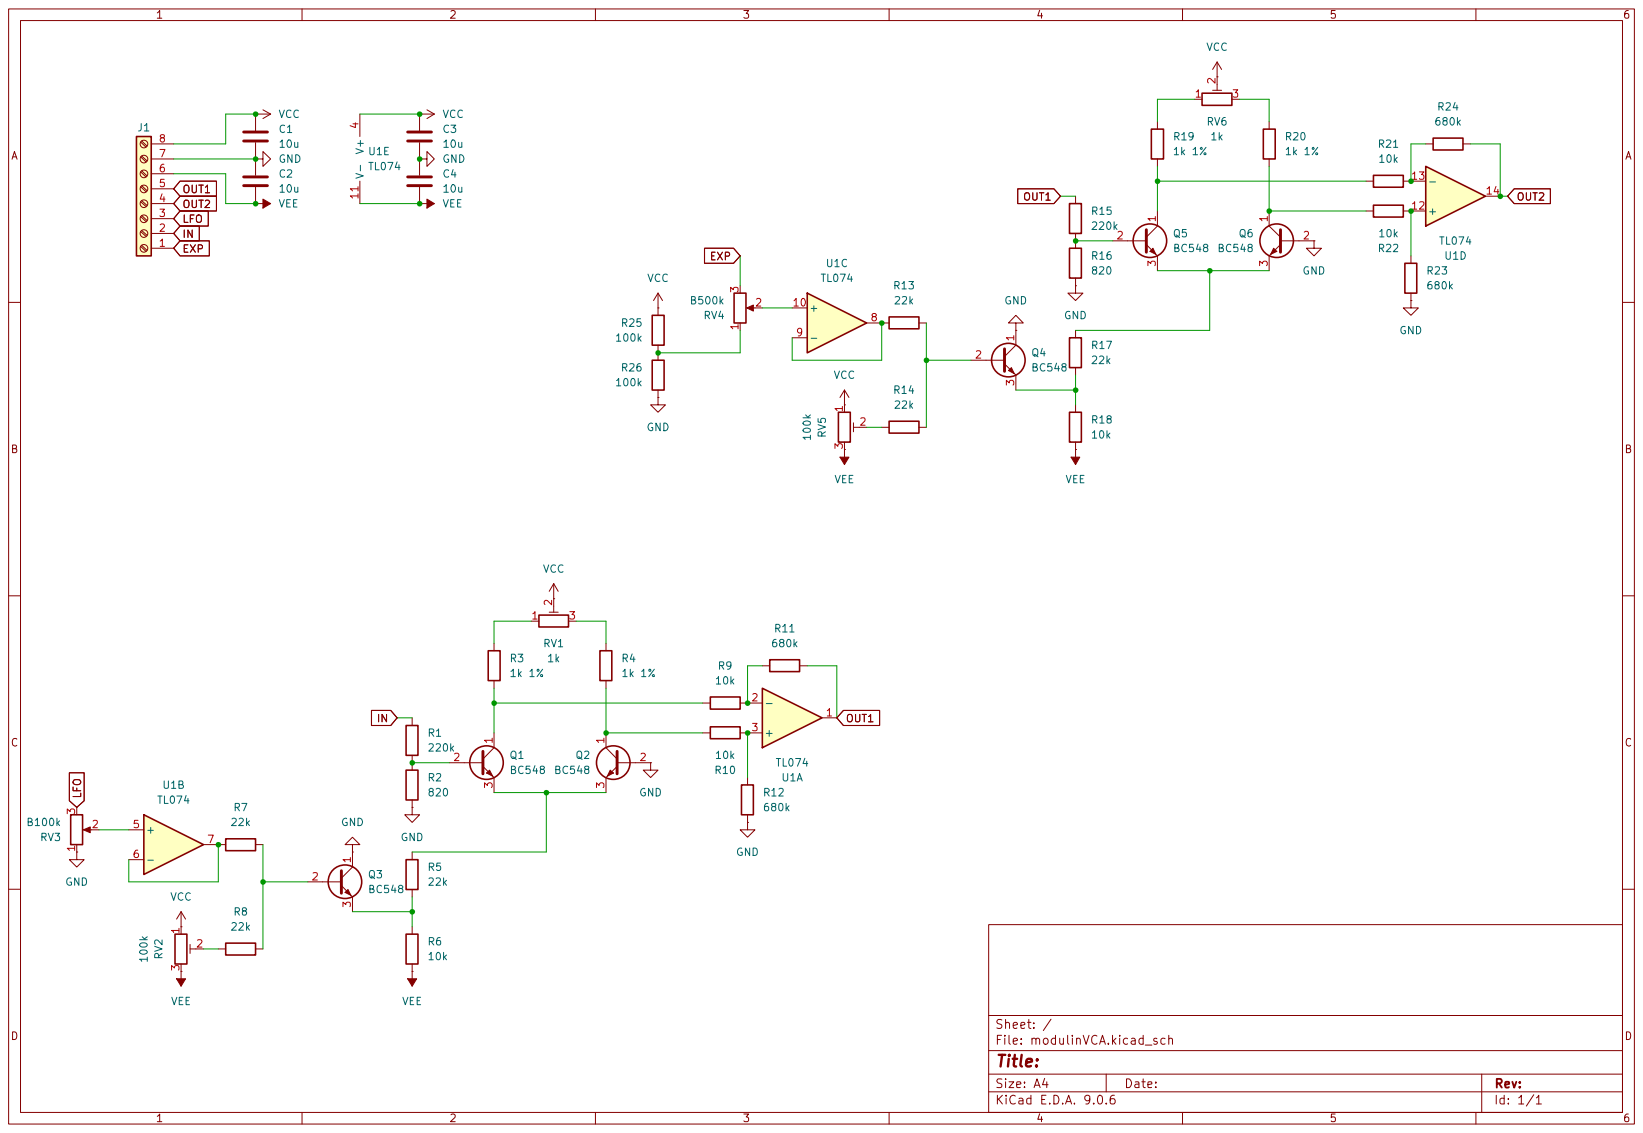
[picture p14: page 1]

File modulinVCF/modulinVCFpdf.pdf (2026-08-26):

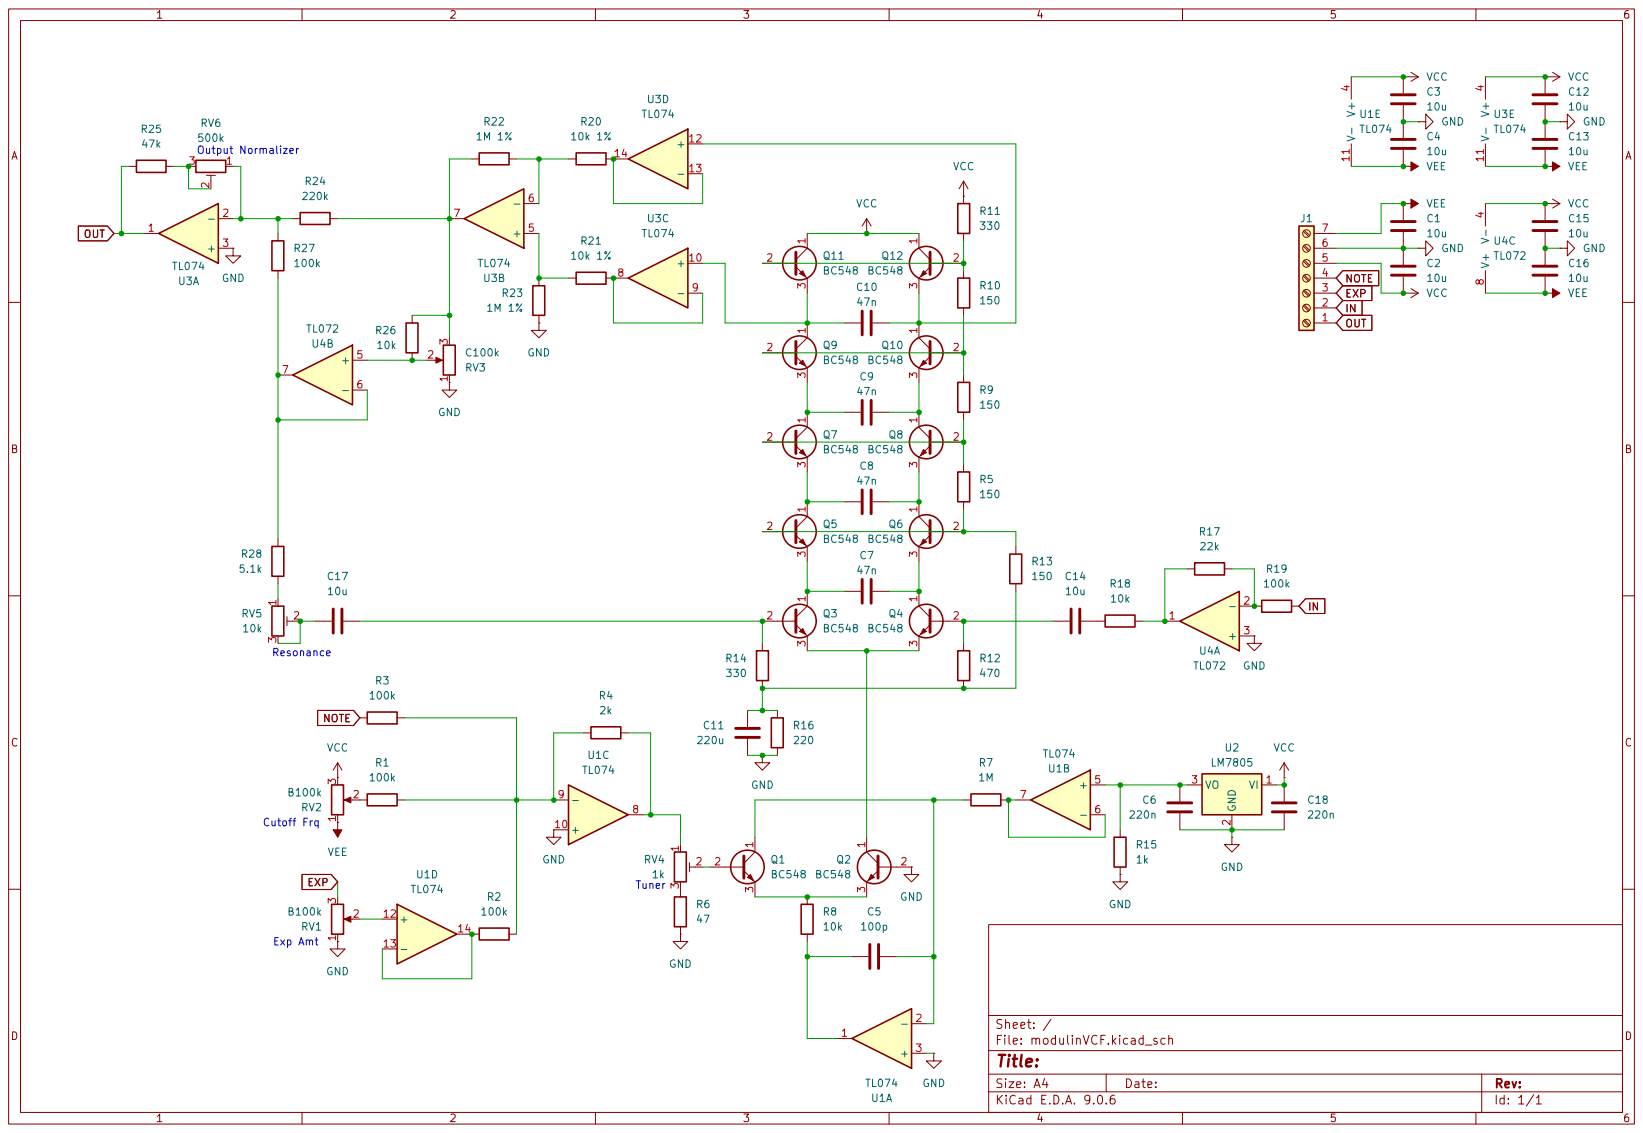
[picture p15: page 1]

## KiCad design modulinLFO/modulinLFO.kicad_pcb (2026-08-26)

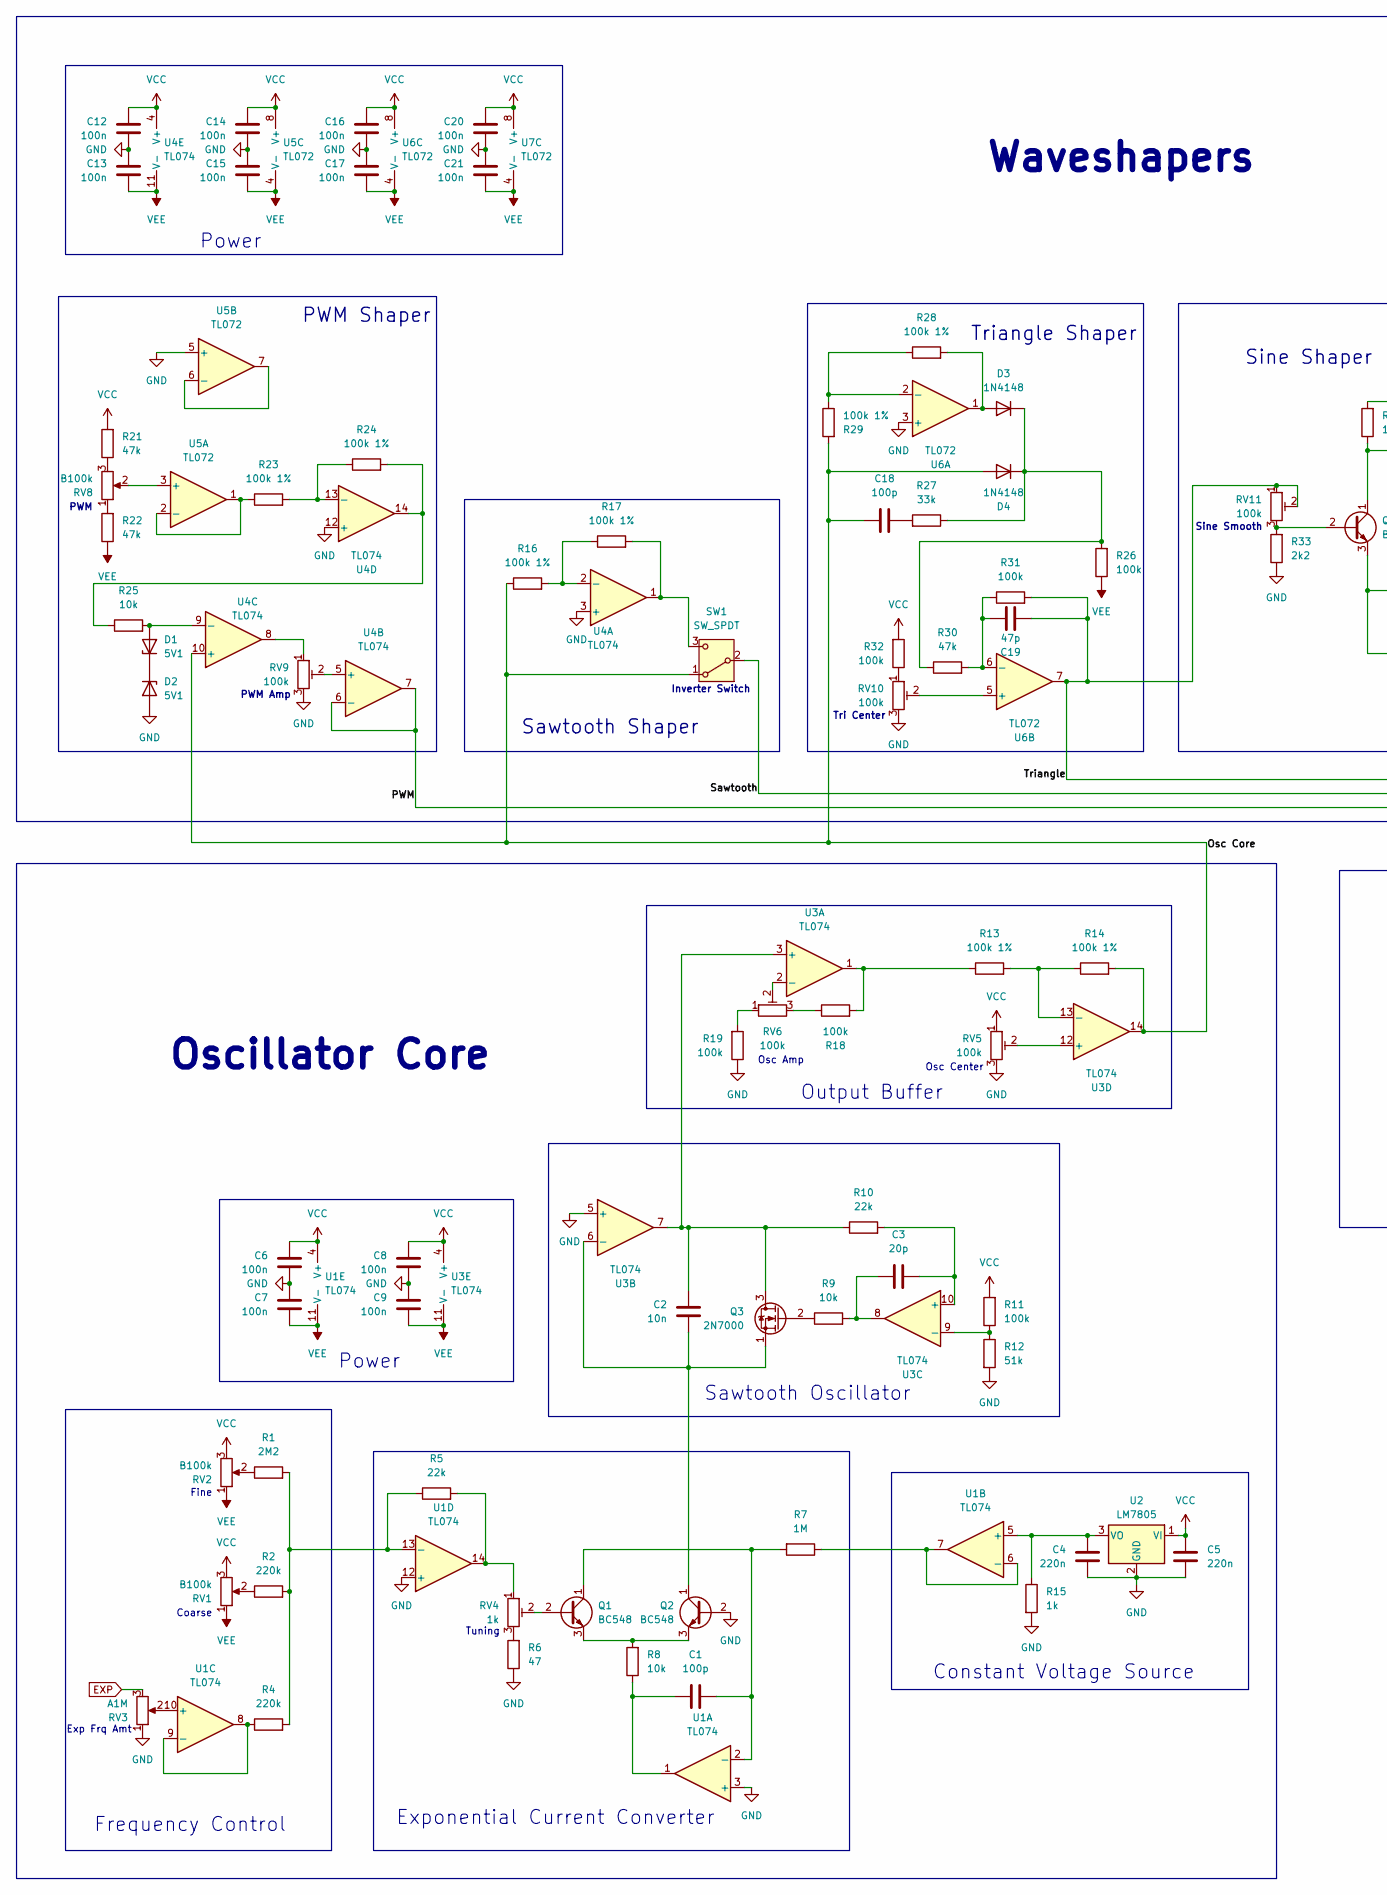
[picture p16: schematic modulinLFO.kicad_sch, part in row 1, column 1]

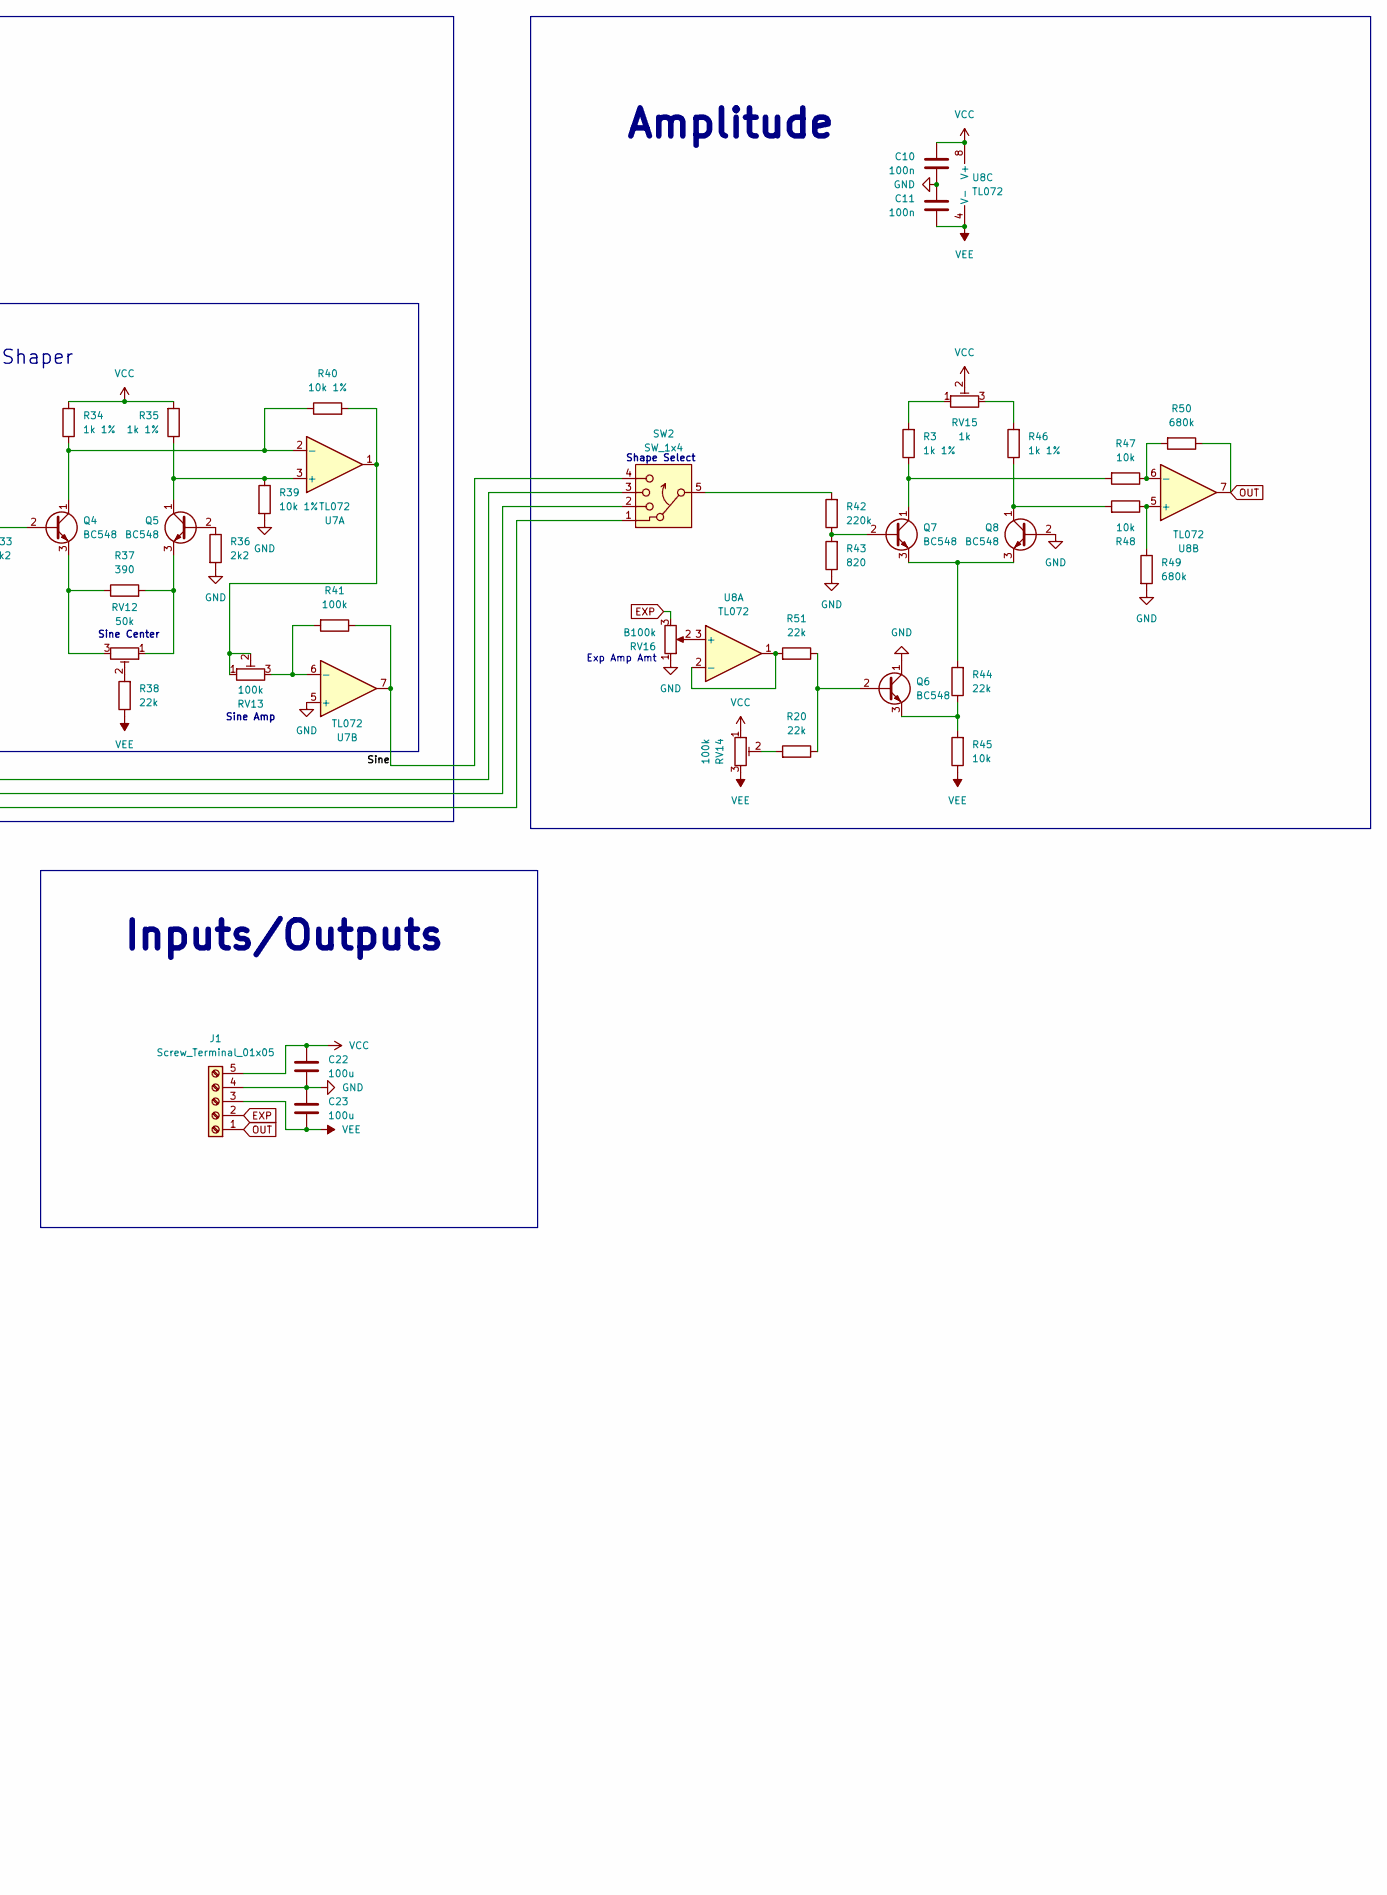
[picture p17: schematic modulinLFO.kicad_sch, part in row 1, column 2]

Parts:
C1: 100p; C_Axial_P5.00mm_CNC
C2: 10n; C_Rect_P5.00mm_CNC
C3: 20p; C_Axial_P5.00mm_CNC
C4, C5: 220n; C_Axial_P5.00mm_CNC
C6, C7, C8, C9, C10, C11, C12, C13, C14, C15, C16, C17, C20, C21: 100n; C_Axial_P5.00mm_CNC
C18: 100p; C_Rect_P5.00mm_CNC
C19: 47p; C_Rect_P5.00mm_CNC
C22, C23: 100u; C_Radial_Polarized_P2.5mm_CNC
D1: 5V1; D_P2.54mm_CNC
D2: 5V1; D_P5.08mm_CNC
D3, D4: 1N4148; D_P7.62mm_CNC
J1: Screw_Terminal_01x05; TerminalBlock_1x5_CNC
Q1, Q2, Q4, Q5, Q6, Q7, Q8: BC548; TO-92_CNC
Q3: 2N7000; TO-92_CNC
R1: 2M2; R_10.16mm_CNC
R2, R42: 220k; R_10.16mm_CNC
R3, R46: 1k 1%; R_7.62mm_CNC
R4: 220k; R_2.54mm_CNC
R5: 22k; R_2.54mm_CNC
R6: 47; R_5.08mm_CNC
R7: 1M; R_10.16mm_CNC
R8, R9, R25, R45, R47, R48: 10k; R_10.16mm_CNC
R10, R38, R44, R51: 22k; R_10.16mm_CNC
R11: 100k; R_7.62mm_CNC
R12: 51k; R_5.08mm_CNC
R13, R16, R23: 100k 1%; R_10.16mm_CNC
R14, R17, R24, R28: 100k 1%; R_2.54mm_CNC
R15: 1k; R_7.62mm_CNC
R18, R31: 100k; R_2.54mm_CNC
R19, R41: 100k; R_2.54mm_CNC_Alt
R20: 22k; R_7.62mm_CNC
R21: 47k; R_7.62mm_CNC
R22, R30: 47k; R_10.16mm_CNC
R26, R32: 100k; R_10.16mm_CNC
R27: 33k; R_2.54mm_CNC_Alt
R29: 100k 1%; R_7.62mm_CNC
R33, R36: 2k2; R_10.16mm_CNC
R34, R35: 1k 1%; R_10.16mm_CNC
R37: 390; R_5.08mm_CNC
R39: 10k 1%; R_10.16mm_CNC
R40: 10k 1%; R_2.54mm_CNC_Alt
R43: 820; R_10.16mm_CNC
R49: 680k; R_10.16mm_CNC
R50: 680k; R_7.62mm_CNC
RV1, RV2, RV8, RV16: B100k; Potentiometer_PanelMount_CNC
RV3: A1M; Potentiometer_PanelMount_CNC
RV4, RV15: 1k; Potentiometer_Trim_CNC
RV5, RV6, RV9, RV10, RV11, RV13, RV14: 100k; Potentiometer_Trim_CNC
RV12: 50k; Potentiometer_Trim_CNC
SW1: SW_SPDT; SW_Slide_SPDT_H6.00mm_CNC
SW2: SW_1x4; SW_Slide_SP4T_H6.00mm_CNC
U1, U3, U4: TL074; DIP-14_CNC
U2: LM7805; TO-220_CNC
U5, U6, U7, U8: TL072; DIP-8_CNC

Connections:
/Osc Core: C18.1, D4.2 (A), R14.2, R16.1, R29.2, SW1.1 (A), U3.14, U4.10 (+)
/PWM: SW2.1, U4.6 (-), U4.7
/Sawtooth: SW1.2 (B), SW2.2
/Sine: R41.1, SW2.4, U7.7
/Triangle: C19.2, R31.2, RV11.1, RV11.2, SW2.3, U6.7
EXP: J1.2, RV3.3, RV16.3
GND: C4.1, C5.1, C6.2, C7.1, C8.2, C9.1, C10.2, C11.1, C12.2, C13.1, C14.2, C15.1, C16.2, C17.1, C20.2, C21.1, C22.1, C23.2, D2.2 (A), J1.4, Q2.2 (B), Q6.1 (C), Q8.2 (B), R6.1, R12.2, R15.2, R19.1, R33.1, R36.2, R39.2, R43.1, R49.2, RV3.1, RV5.3, RV9.3, RV10.3, RV16.1, U1.3 (+), U1.12 (+), U2.2 (GND), U3.5 (+), U4.3 (+), U4.12 (+), U5.5 (+), U6.3 (+), U7.5 (+)
unnamed: C1.1, R8.1, U1.1
unnamed: C3.1, R9.2, U3.8
unnamed: C18.2, R27.2
unnamed: D1.2 (A), R25.2, U4.9 (-)
unnamed: D1.1 (K), D2.1 (K)
unnamed: D3.2 (A), R28.2, U6.1
unnamed: D3.1 (K), D4.1 (K), R26.2, R27.1, R30.1
unnamed: Q1.2 (B), RV4.2
unnamed: C1.2, Q1.1 (C), R7.2, U1.2 (-)
unnamed: Q1.3 (E), Q2.3 (E), R8.2
unnamed: C2.2, Q2.1 (C), Q3.1 (S), U3.6 (-)
unnamed: C2.1, Q3.3 (D), R10.1, U3.3 (+), U3.7
unnamed: Q3.2 (G), R9.1
unnamed: Q4.2 (B), R33.2, RV11.3
unnamed: Q4.1 (C), R34.1, R40.1, U7.2 (-)
unnamed: Q4.3 (E), R37.1, RV12.3
unnamed: Q5.2 (B), R36.1
unnamed: Q5.1 (C), R35.1, R39.1, U7.3 (+)
unnamed: Q5.3 (E), R37.2, RV12.1
unnamed: Q6.2 (B), R20.1, R51.1
unnamed: Q6.3 (E), R44.1, R45.2
unnamed: Q7.2 (B), R42.1, R43.2
unnamed: Q7.1 (C), R3.1, R47.2
unnamed: Q7.3 (E), Q8.3 (E), R44.2
unnamed: Q8.1 (C), R46.1, R48.2
unnamed: R1.1, RV2.2
unnamed: R2.1, RV1.2
unnamed: R3.2, RV15.1
unnamed: R5.2, RV4.1, U1.14
unnamed: R6.2, RV4.3
unnamed: R13.1, R18.2, U3.1
unnamed: R18.1, RV6.3
unnamed: R19.2, RV6.1
unnamed: R20.2, RV14.2
unnamed: R21.1, RV8.3
unnamed: R22.2, RV8.1
unnamed: R24.2, R25.1, U4.14
unnamed: R32.1, RV10.1
unnamed: R38.2, RV12.2
unnamed: R40.2, RV13.1, RV13.2, U7.1
unnamed: R42.2, SW2.5
unnamed: R46.2, RV15.3
unnamed: RV9.1, U4.8
unnamed: R17.2, SW1.3 (C), U4.1
unnamed: C4.2, R15.1, U1.5 (+), U2.3 (VO)
unnamed: R7.1, U1.6 (-), U1.7
unnamed: RV3.2, U1.10 (+)
unnamed: R4.1, U1.8, U1.9 (-)
unnamed: R1.2, R2.2, R4.2, R5.1, U1.13 (-)
unnamed: RV6.2, U3.2 (-)
unnamed: C3.2, R10.2, U3.10 (+)
unnamed: R11.1, R12.1, U3.9 (-)
unnamed: RV5.2, U3.12 (+)
unnamed: R13.2, R14.1, U3.13 (-)
unnamed: R16.2, R17.1, U4.2 (-)
unnamed: RV9.2, U4.5 (+)
unnamed: R23.2, R24.1, U4.13 (-)
unnamed: RV8.2, U5.3 (+)
unnamed: R23.1, U5.1, U5.2 (-)
unnamed: U5.6 (-), U5.7
unnamed: R28.1, R29.1, U6.2 (-)
unnamed: RV10.2, U6.5 (+)
unnamed: C19.1, R30.2, R31.1, U6.6 (-)
unnamed: R41.2, RV13.3, U7.6 (-)
unnamed: RV16.2, U8.3 (+)
unnamed: R51.2, U8.1, U8.2 (-)
unnamed: R48.1, R49.1, U8.5 (+)
unnamed: R47.1, R50.2, U8.6 (-)
OUT: J1.1, R50.1, U8.7
VCC: C5.2, C6.1, C8.1, C10.1, C12.1, C14.1, C16.1, C20.1, C22.2, J1.5, R11.2, R21.2, R32.2, R34.2, R35.2, RV1.3, RV2.3, RV5.1, RV14.1, RV15.2, U1.4 (V+), U2.1 (VI), U3.4 (V+), U4.4 (V+), U5.8 (V+), U6.8 (V+), U7.8 (V+), U8.8 (V+)
VEE: C7.2, C9.2, C11.2, C13.2, C15.2, C17.2, C21.2, C23.1, J1.3, R22.1, R26.1, R38.1, R45.1, RV1.1, RV2.1, RV14.3, U1.11 (V-), U3.11 (V-), U4.11 (V-), U5.4 (V-), U6.4 (V-), U7.4 (V-), U8.4 (V-)

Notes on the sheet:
Constant Voltage Source
Power
Sine Amp
Triangle Shaper
PWM Shaper
Tuning
Exp Frq Amt
Output Buffer
Inputs/Outputs
Shape Select
Sine Shaper
Sawtooth Shaper
Inverter Switch
Tri Center
PWM Amp
Osc Center
Exponential Current Converter
Fine
Coarse
Oscillator Core
Osc Amp
Waveshapers
Sine Smooth
Sine Center
Amplitude
Sawtooth Oscillator
Exp Amp Amt
Frequency Control
PWM

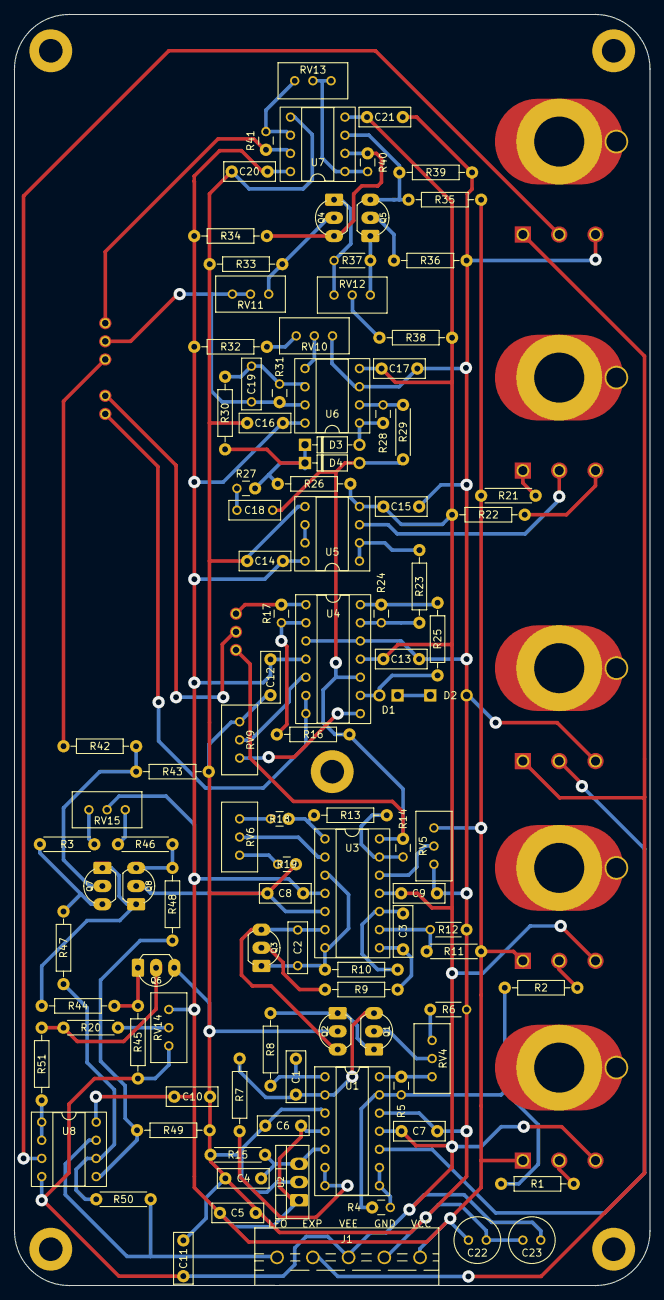
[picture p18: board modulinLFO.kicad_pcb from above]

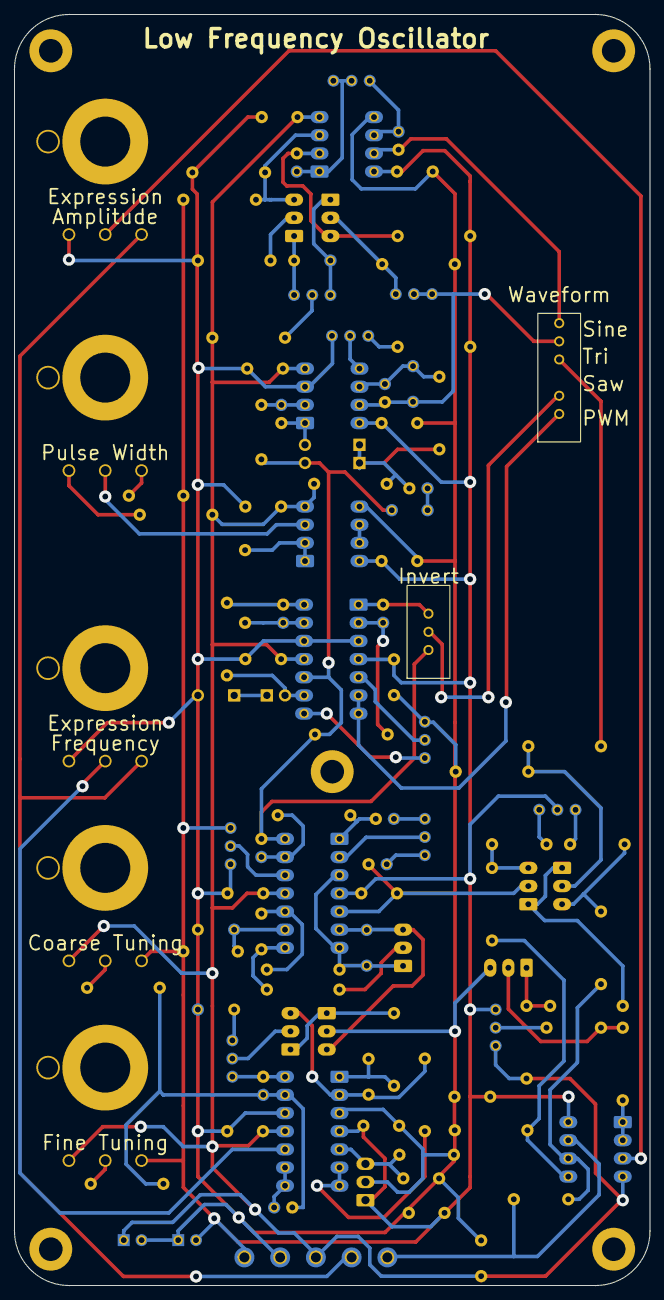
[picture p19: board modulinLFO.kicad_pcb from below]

Board: 2 copper layers, 88.9 x 177.8 mm, 112 parts (7 on the bottom side), 78 nets.

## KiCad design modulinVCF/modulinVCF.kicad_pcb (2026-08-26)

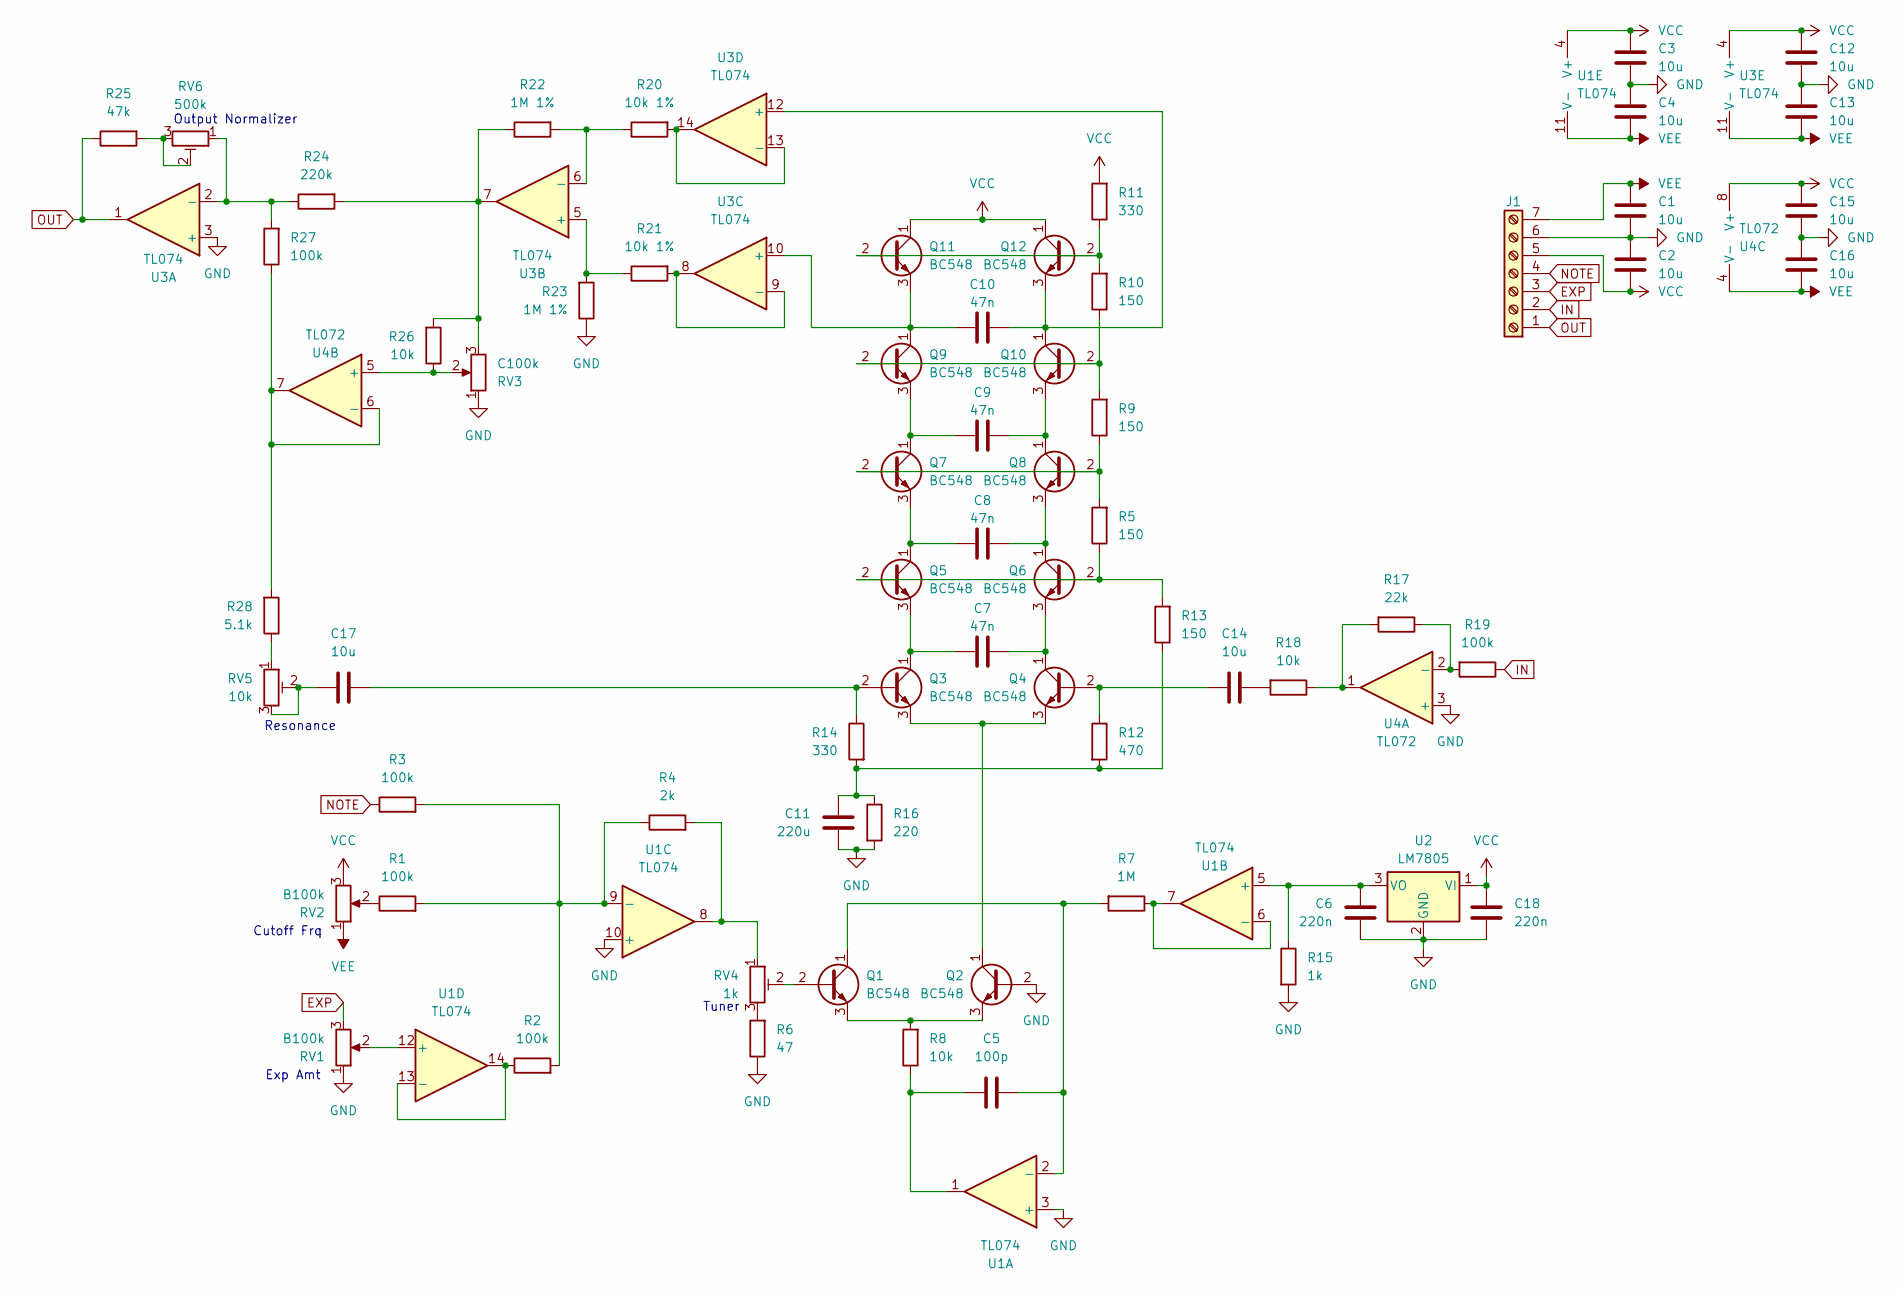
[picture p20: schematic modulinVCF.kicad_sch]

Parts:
C1, C2, C12: 10u; C_Rect_P5.00mm_CNC
C3, C4, C13, C14, C15, C16, C17: 10u; C_Axial_P5.00mm_CNC
C5: 100p; C_Axial_P5.00mm_CNC
C6, C18: 220n; C_Axial_P5.00mm_CNC
C7, C8, C9, C10: 47n; C_Axial_P5.00mm_CNC
C11: 220u; CP_Radial_D8.0mm_P3.80mm
J1: Screw_Terminal_01x07; TerminalBlock_1x7_CNC
Q1, Q2, Q3, Q4, Q5, Q6, Q7, Q8, Q9, Q10, Q11, Q12: BC548; TO-92_CNC
R1, R2, R3, R19, R27: 100k; R_10.16mm_CNC
R4: 2k; R_2.54mm_CNC
R5, R9, R10: 150; R_7.62mm_CNC
R6: 47; R_5.08mm_CNC
R7: 1M; R_10.16mm_CNC
R8: 10k; R_7.62mm_CNC
R11: 330; R_2.54mm_CNC
R12: 470; R_2.54mm_CNC_Alt
R13: 150; R_2.54mm_CNC
R14: 330; R_7.62mm_CNC
R15: 1k; R_7.62mm_CNC
R16: 220; R_10.16mm_CNC
R17: 22k; R_2.54mm_CNC
R18: 10k; R_5.08mm_CNC
R20, R21: 10k 1%; R_10.16mm_CNC
R22: 1M 1%; R_2.54mm_CNC
R23: 1M 1%; R_7.62mm_CNC
R24: 220k; R_10.16mm_CNC
R25: 47k; R_10.16mm_CNC
R26: 10k; R_10.16mm_CNC
R28: 5.1k; R_2.54mm_CNC
RV1, RV2: B100k; Potentiometer_PanelMount_CNC
RV3: C100k; Potentiometer_PanelMount_CNC
RV4: 1k; Potentiometer_Trim_CNC
RV5: 10k; Potentiometer_Trim_CNC
RV6: 500k; Potentiometer_Trim_CNC
U1, U3: TL074; DIP-14_CNC
U2: LM7805; TO-220_CNC
U4: TL072; DIP-8_CNC

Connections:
EXP: J1.3, RV1.3
GND: C1.2, C2.1, C3.2, C4.1, C6.1, C11.1, C12.2, C13.1, C15.2, C16.1, C18.1, J1.6, Q2.2 (B), R6.1, R15.2, R16.2, R23.1, RV1.1, RV3.1, U1.3 (+), U1.10 (+), U2.2 (GND), U3.3 (+), U4.3 (+)
IN: J1.2, R19.1
NOTE: J1.4, R3.1
unnamed: C5.1, R8.1, U1.1
unnamed: C11.2, R12.2, R13.1, R14.2, R16.1
unnamed: C14.1, R18.2
unnamed: C17.2, RV5.2, RV5.3
unnamed: Q1.2 (B), RV4.2
unnamed: C5.2, Q1.1 (C), R7.2, U1.2 (-)
unnamed: Q1.3 (E), Q2.3 (E), R8.2
unnamed: Q2.1 (C), Q3.3 (E), Q4.3 (E)
unnamed: C17.1, Q3.2 (B), R14.1
unnamed: C7.2, Q3.1 (C), Q5.3 (E)
unnamed: C14.2, Q4.2 (B), R12.1
unnamed: C7.1, Q4.1 (C), Q6.3 (E)
unnamed: Q5.2 (B), Q6.2 (B), R5.1, R13.2
unnamed: C8.2, Q5.1 (C), Q7.3 (E)
unnamed: C8.1, Q6.1 (C), Q8.3 (E)
unnamed: Q7.2 (B), Q8.2 (B), R5.2, R9.1
unnamed: C9.2, Q7.1 (C), Q9.3 (E)
unnamed: Q9.2 (B), Q10.2 (B), R9.2, R10.1
unnamed: C10.1, Q10.1 (C), Q12.3 (E), U3.12 (+)
unnamed: C9.1, Q8.1 (C), Q10.3 (E)
unnamed: Q11.2 (B), Q12.2 (B), R10.2, R11.1
unnamed: C10.2, Q9.1 (C), Q11.3 (E), U3.10 (+)
unnamed: R1.1, RV2.2
unnamed: R4.2, RV4.1, U1.8
unnamed: R6.2, RV4.3
unnamed: R17.2, R18.1, U4.1
unnamed: R22.1, R24.2, R26.2, RV3.3, U3.7
unnamed: R25.2, RV6.2, RV6.3
unnamed: R28.1, RV5.1
unnamed: C6.2, R15.1, U1.5 (+), U2.3 (VO)
unnamed: R7.1, U1.6 (-), U1.7
unnamed: R1.2, R2.2, R3.2, R4.1, U1.9 (-)
unnamed: RV1.2, U1.12 (+)
unnamed: R2.1, U1.13 (-), U1.14
unnamed: R24.1, R27.2, RV6.1, U3.2 (-)
unnamed: R21.1, R23.2, U3.5 (+)
unnamed: R20.1, R22.2, U3.6 (-)
unnamed: R21.2, U3.8, U3.9 (-)
unnamed: R20.2, U3.13 (-), U3.14
unnamed: R17.1, R19.2, U4.2 (-)
unnamed: R26.1, RV3.2, U4.5 (+)
unnamed: R27.1, R28.2, U4.6 (-), U4.7
OUT: J1.1, R25.1, U3.1
VCC: C2.2, C3.1, C12.1, C15.1, C18.2, J1.5, Q11.1 (C), Q12.1 (C), R11.2, RV2.3, U1.4 (V+), U2.1 (VI), U3.4 (V+), U4.8 (V+)
VEE: C1.1, C4.2, C13.2, C16.2, J1.7, RV2.1, U1.11 (V-), U3.11 (V-), U4.4 (V-)

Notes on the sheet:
Output Normalizer
Resonance
Tuner
Exp Amt
Cutoff Frq

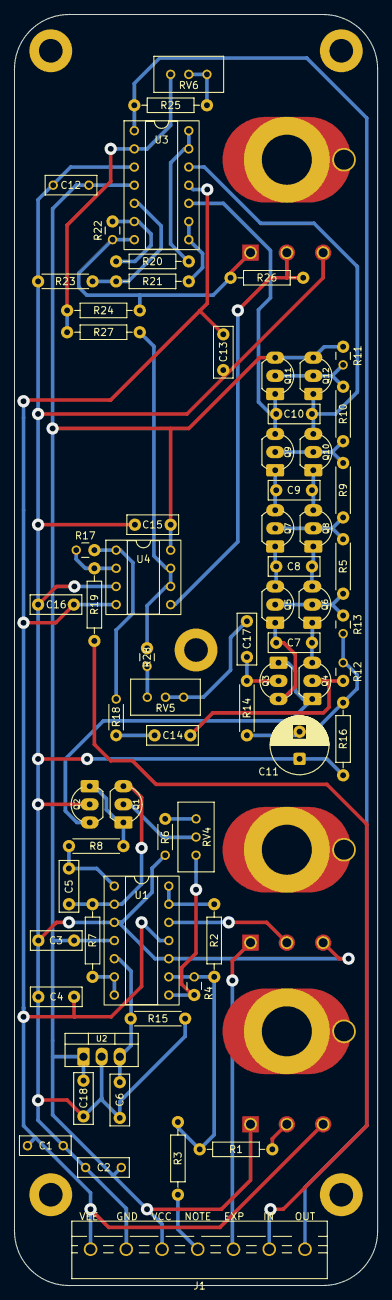
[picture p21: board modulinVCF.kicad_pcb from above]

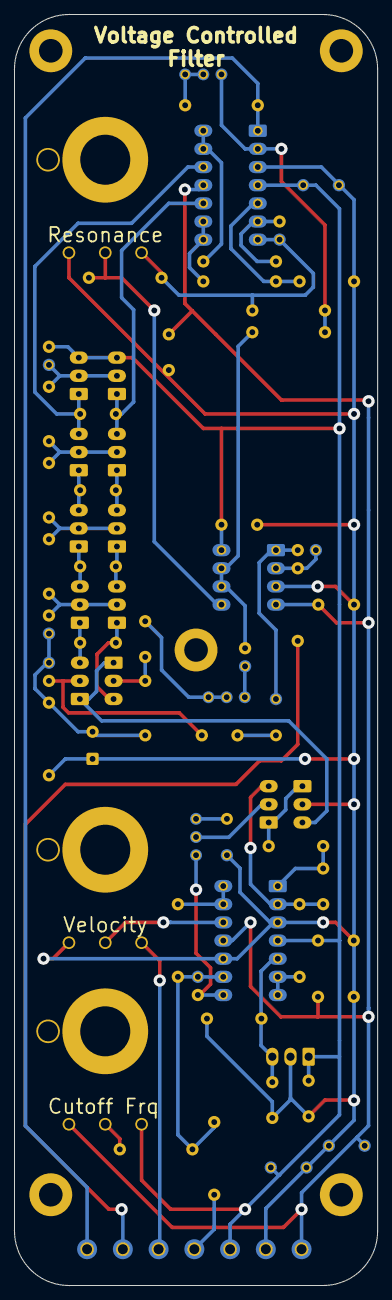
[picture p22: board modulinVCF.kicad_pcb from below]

Board: 2 copper layers, 50.8 x 177.8 mm, 69 parts (3 on the bottom side), 49 nets.

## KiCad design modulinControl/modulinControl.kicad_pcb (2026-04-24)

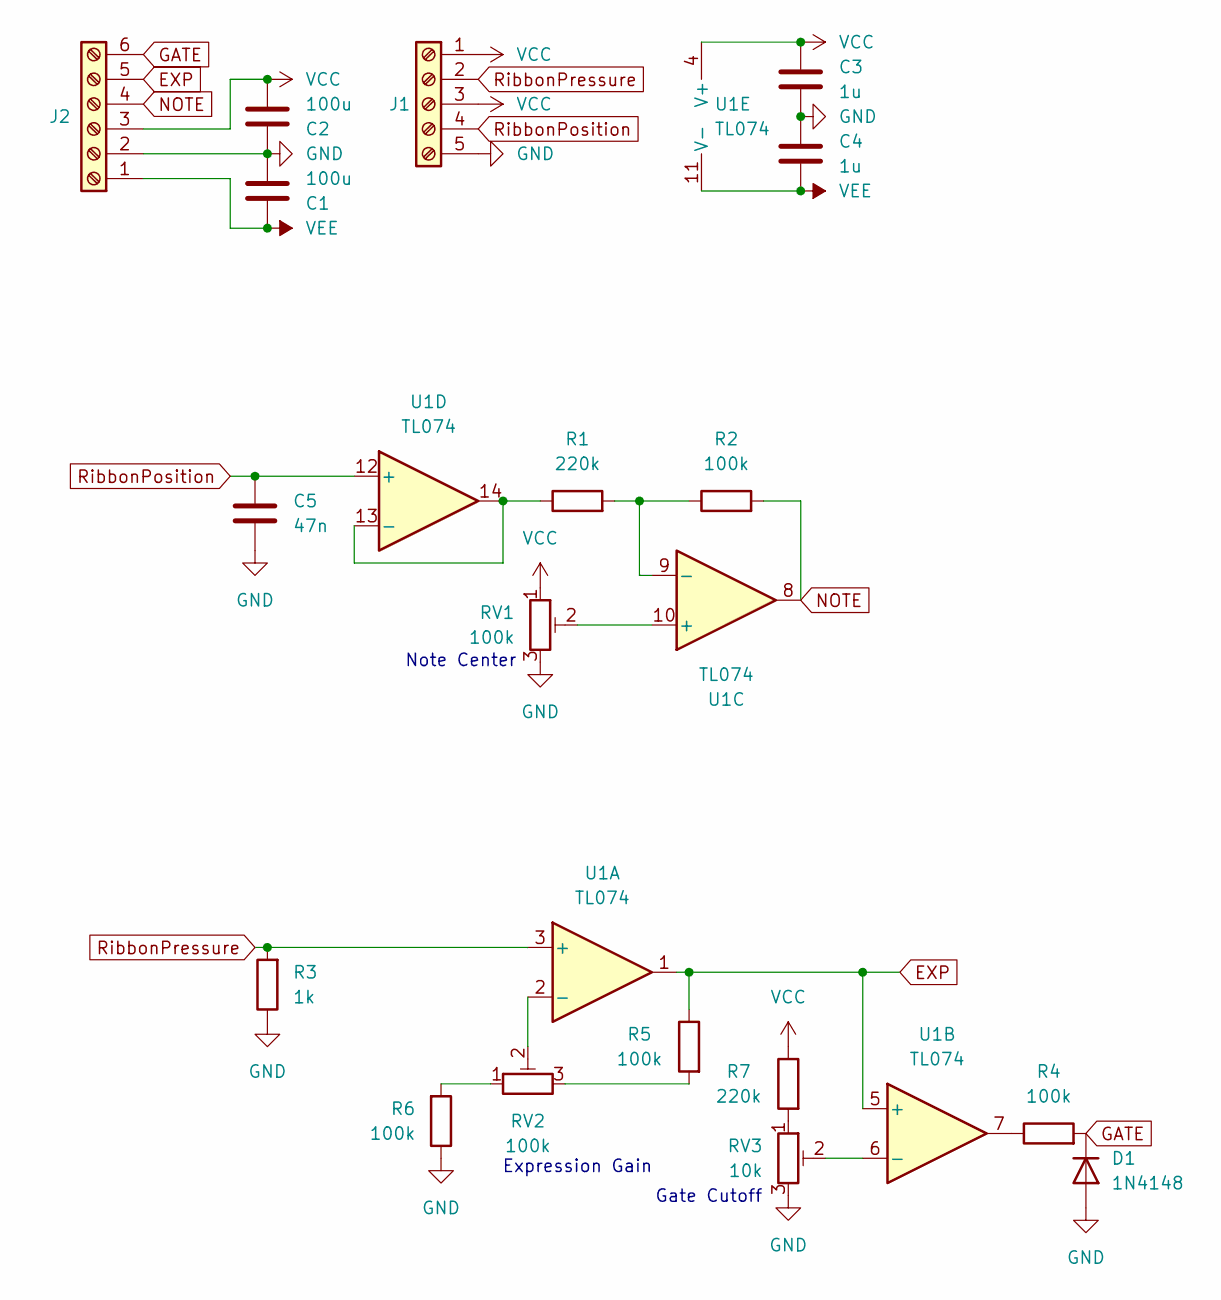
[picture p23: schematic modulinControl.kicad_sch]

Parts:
C1, C2: 100u; C_Radial_Polarized_P3.8mm_CNC
C3, C4: 1u; C_Axial_P5.00mm_CNC
C5: 47n; C_Axial_P5.00mm_CNC
D1: 1N4148; D_P7.62mm_CNC
J1: Screw_Terminal_01x05; TerminalBlock_1x5_CNC
J2: Screw_Terminal_01x06; TerminalBlock_1x6_CNC
R1, R7: 220k; R_10.16mm_CNC
R2, R4, R5, R6: 100k; R_10.16mm_CNC
R3: 1k; R_10.16mm_CNC
RV1, RV2: 100k; Potentiometer_Trim_CNC
RV3: 10k; Potentiometer_Trim_CNC
U1: TL074; DIP-14_CNC

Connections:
EXP: J2.5, R5.1, U1.1, U1.5 (+)
GATE: D1.1 (K), J2.6, R4.2
GND: C1.2, C2.1, C3.2, C4.1, C5.2, D1.2 (A), J1.5, J2.2, R3.1, R6.1, RV1.3, RV3.3
NOTE: J2.4, R2.2, U1.8
unnamed: R4.1, U1.7
unnamed: R5.2, RV2.3
unnamed: R6.2, RV2.1
unnamed: R7.2, RV3.1
unnamed: RV2.2, U1.2 (-)
unnamed: RV3.2, U1.6 (-)
unnamed: RV1.2, U1.10 (+)
unnamed: R1.2, R2.1, U1.9 (-)
unnamed: R1.1, U1.13 (-), U1.14
RibbonPosition: C5.1, J1.4, U1.12 (+)
RibbonPressure: J1.2, R3.2, U1.3 (+)
VCC: C2.2, C3.1, J1.1, J1.3, J2.3, R7.1, RV1.1, U1.4 (V+)
VEE: C1.1, C4.2, J2.1, U1.11 (V-)

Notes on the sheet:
Note Center
Gate Cutoff
Expression Gain

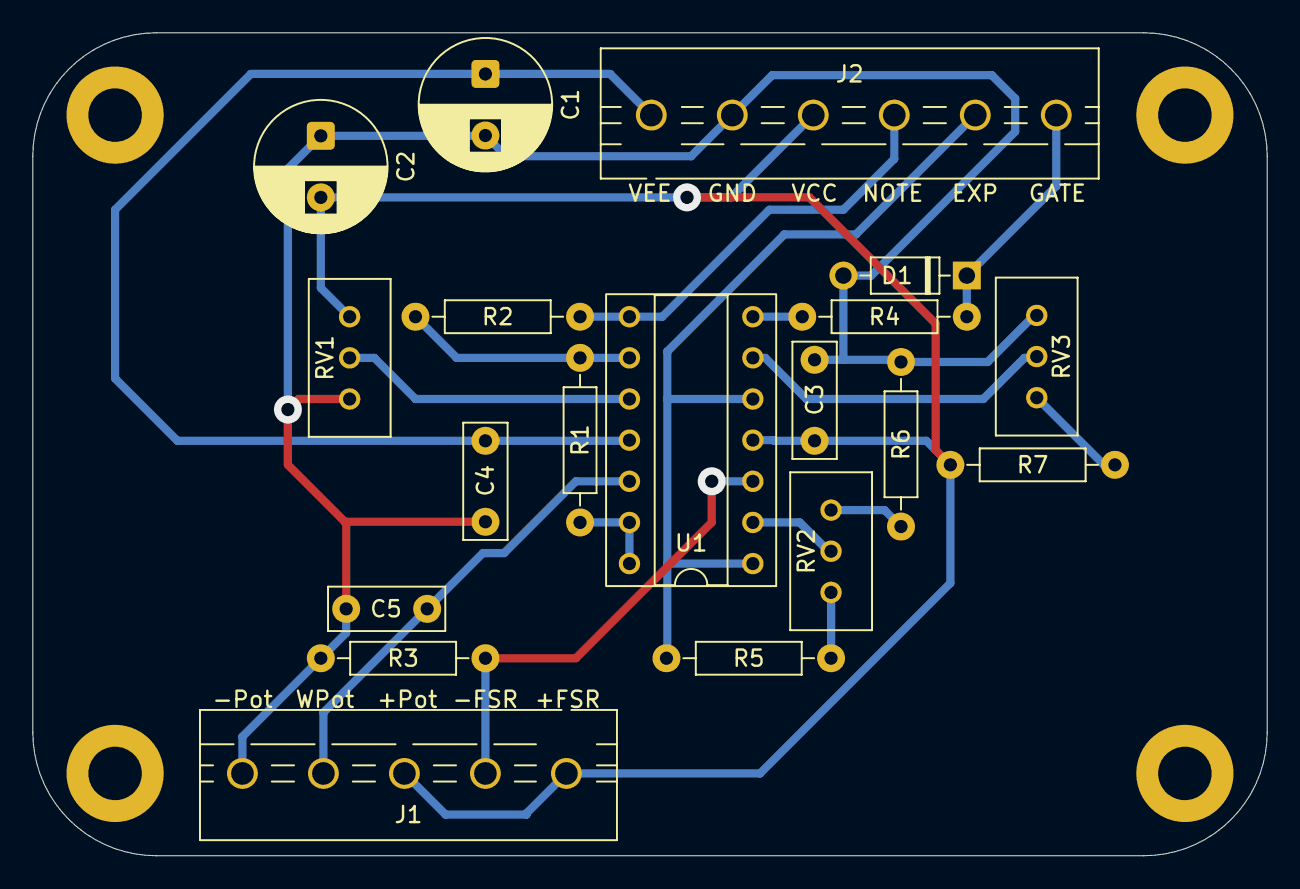
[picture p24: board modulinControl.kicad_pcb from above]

Board: 2 copper layers, 76.2 x 50.8 mm, 19 parts (0 on the bottom side), 17 nets.

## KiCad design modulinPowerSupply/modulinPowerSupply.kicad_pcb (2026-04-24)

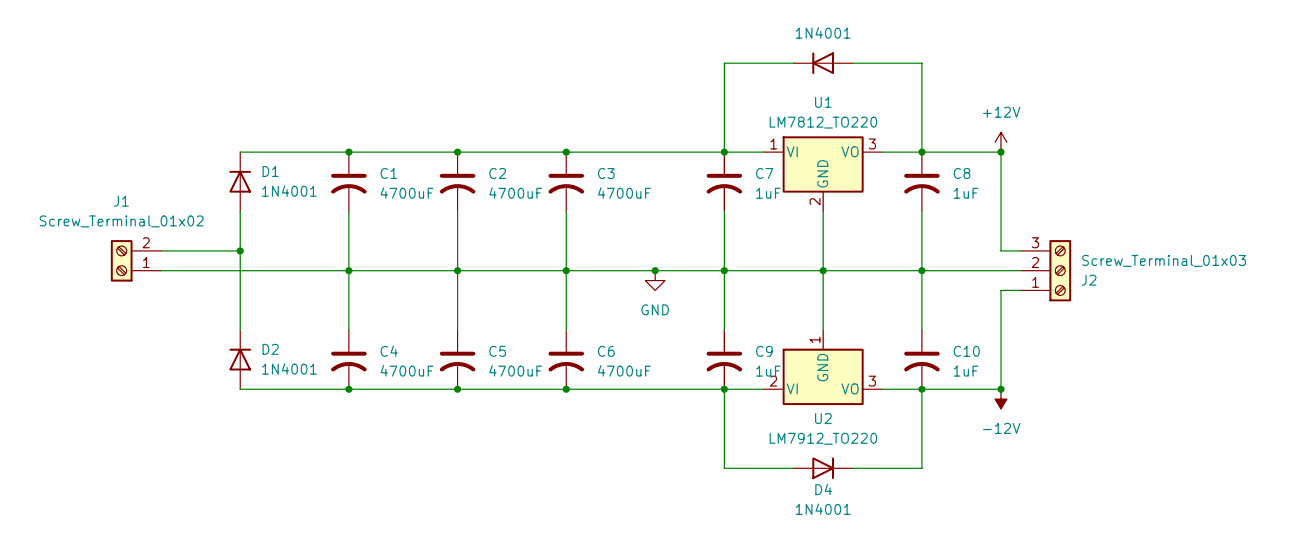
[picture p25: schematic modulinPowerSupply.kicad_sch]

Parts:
C1, C2, C3, C4, C5, C6: 4700uF; C_Radial_Polarized_P7.50mm_CNC
C7, C8, C9, C10: 1uF; C_Rect_P5.00mm_CNC
D1, D2, D3, D4: 1N4001; D_P10.16mm_CNC
J1: Screw_Terminal_01x02; TerminalBlock_1x2_CNC
J2: Screw_Terminal_01x03; TerminalBlock_1x3_CNC
U1: LM7812_TO220; TO-220_CNC
U2: LM7912_TO220; TO-220_CNC

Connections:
+12V: C8.1, D3.2 (A), J2.3, U1.3 (VO)
-12V: C10.2, D4.1 (K), J2.1, U2.3 (VO)
GND: C1.2, C2.2, C3.2, C4.1, C5.1, C6.1, C7.2, C8.2, C9.1, C10.1, J1.1, J2.2, U1.2 (GND), U2.1 (GND)
unnamed: D1.2 (A), D2.1 (K), J1.2
unnamed: C1.1, C2.1, C3.1, C7.1, D1.1 (K), D3.1 (K), U1.1 (VI)
unnamed: C4.2, C5.2, C6.2, C9.2, D2.2 (A), D4.2 (A), U2.2 (VI)

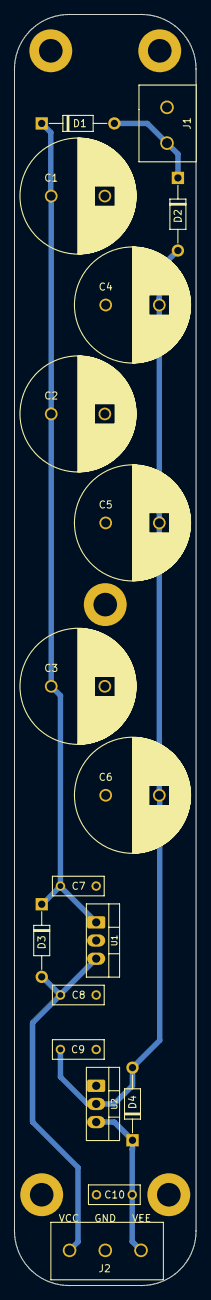
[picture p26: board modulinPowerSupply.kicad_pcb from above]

Board: 2 copper layers, 25.4 x 177.8 mm, 18 parts (0 on the bottom side), 6 nets.

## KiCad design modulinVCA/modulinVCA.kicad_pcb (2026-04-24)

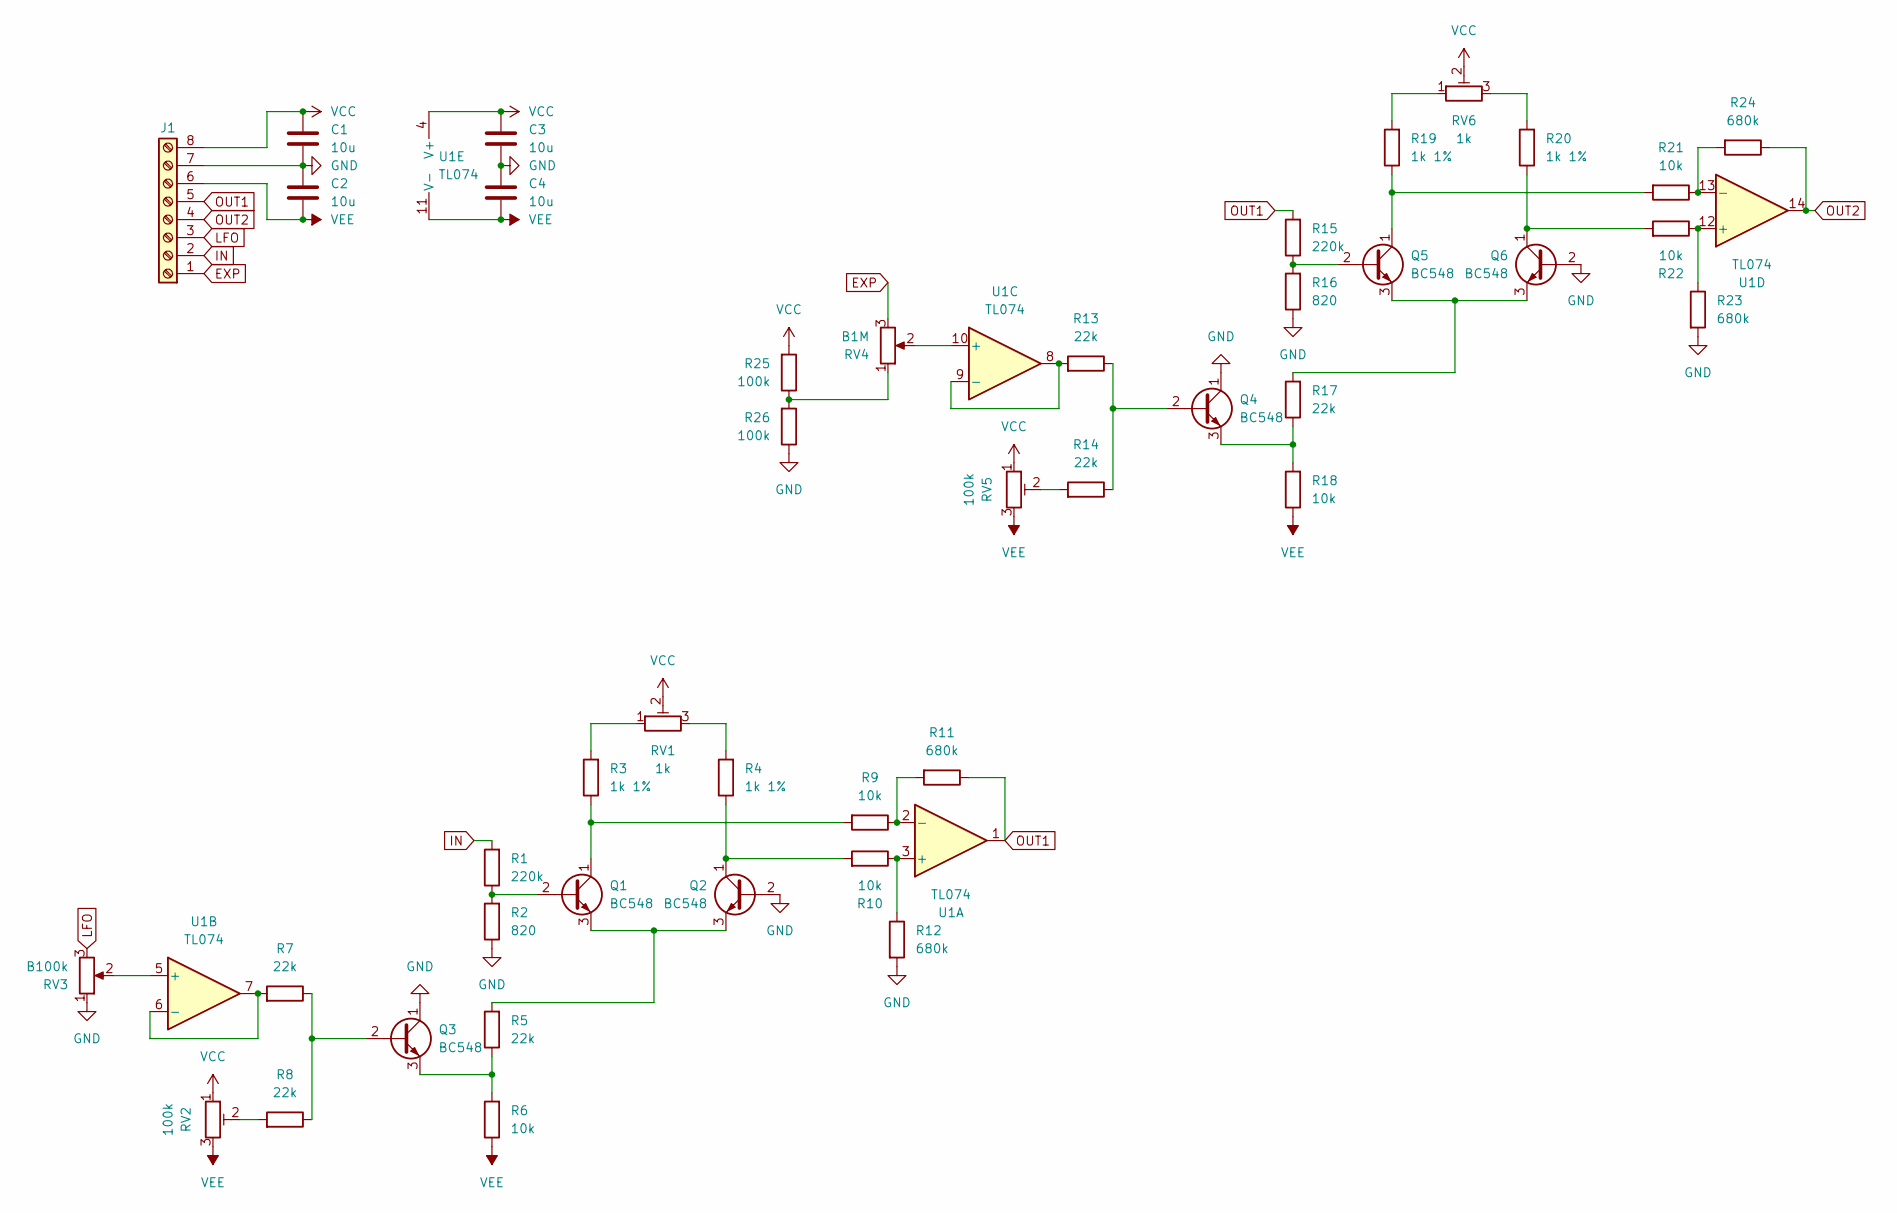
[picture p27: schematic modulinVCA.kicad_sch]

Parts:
C1, C2, C3, C4: 10u; C_Axial_P5.00mm_CNC
J1: Screw_Terminal_01x08; TerminalBlock_1x8_CNC
Q1, Q2, Q3, Q4, Q5, Q6: BC548; TO-92_CNC
R1, R15: 220k; R_2.54mm_CNC
R2: 820; R_2.54mm_CNC
R3, R20: 1k 1%; R_7.62mm_CNC
R4, R19: 1k 1%; R_2.54mm_CNC
R5, R17: 22k; R_10.16mm_CNC
R6, R18: 10k; R_2.54mm_CNC_Alt
R7, R13: 22k; R_5.08mm_CNC
R8, R14: 22k; R_2.54mm_CNC
R9: 10k; R_10.16mm_CNC
R10, R22: 10k; R_2.54mm_CNC
R11, R24: 680k; R_2.54mm_CNC
R12, R23: 680k; R_5.08mm_CNC
R16: 820; R_2.54mm_CNC_Alt
R21: 10k; R_7.62mm_CNC
R25, R26: 100k; R_10.16mm_CNC
RV1, RV6: 1k; Potentiometer_Trim_CNC
RV2, RV5: 100k; Potentiometer_Trim_CNC
RV3: B100k; Potentiometer_PanelMount_CNC
RV4: B1M; Potentiometer_PanelMount_CNC
U1: TL074; DIP-14_CNC

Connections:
EXP: J1.1, RV4.3
GND: C1.2, C2.1, C3.2, C4.1, J1.7, Q2.2 (B), Q3.1 (C), Q4.1 (C), Q6.2 (B), R2.1, R12.2, R16.1, R23.2, R26.1, RV3.1
IN: J1.2, R1.2
LFO: J1.3, RV3.3
unnamed: Q1.2 (B), R1.1, R2.2
unnamed: Q1.1 (C), R3.1, R9.2
unnamed: Q1.3 (E), Q2.3 (E), R5.2
unnamed: Q2.1 (C), R4.1, R10.2
unnamed: Q3.2 (B), R7.1, R8.1
unnamed: Q3.3 (E), R5.1, R6.2
unnamed: Q4.2 (B), R13.1, R14.1
unnamed: Q4.3 (E), R17.1, R18.2
unnamed: Q5.2 (B), R15.1, R16.2
unnamed: Q5.1 (C), R19.1, R21.2
unnamed: Q5.3 (E), Q6.3 (E), R17.2
unnamed: Q6.1 (C), R20.1, R22.2
unnamed: R3.2, RV1.1
unnamed: R4.2, RV1.3
unnamed: R8.2, RV2.2
unnamed: R14.2, RV5.2
unnamed: R19.2, RV6.1
unnamed: R20.2, RV6.3
unnamed: R25.1, R26.2, RV4.1
unnamed: R10.1, R12.1, U1.3 (+)
unnamed: R9.1, R11.2, U1.2 (-)
unnamed: RV3.2, U1.5 (+)
unnamed: R7.2, U1.6 (-), U1.7
unnamed: RV4.2, U1.10 (+)
unnamed: R13.2, U1.8, U1.9 (-)
unnamed: R22.1, R23.1, U1.12 (+)
unnamed: R21.1, R24.2, U1.13 (-)
OUT1: J1.5, R11.1, R15.2, U1.1
OUT2: J1.4, R24.1, U1.14
VCC: C1.1, C3.1, J1.8, R25.2, RV1.2, RV2.1, RV5.1, RV6.2, U1.4 (V+)
VEE: C2.2, C4.2, J1.6, R6.1, R18.1, RV2.3, RV5.3, U1.11 (V-)



Board: 2 copper layers, 76.2 x 50.8 mm, 44 parts (2 on the bottom side), 35 nets.

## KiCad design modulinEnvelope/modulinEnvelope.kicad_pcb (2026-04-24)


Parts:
C1: 1n; C_Rect_P5.00mm_CNC
C2: 10n; C_Rect_P5.00mm_CNC
C3: 4u7; C_Rect_P5.00mm_CNC
D1: 1N4148; D_P7.62mm_CNC
D2, D3, D4: 1N4148; D_P10.16mm_CNC
J1: Screw_Terminal_01x06; TerminalBlock_1x6_CNC
Q1, Q2, Q3, Q4, Q5, Q6: BC548; TO-92_CNC
Q7: 2N7000; TO-92_CNC
R1: 220k; R_10.16mm_CNC
R2: 820; R_10.16mm_CNC
R3: 1k 1%; R_7.62mm_CNC
R4: 1k 1%; R_2.54mm_CNC
R5, R7, R8: 22k; R_10.16mm_CNC
R6, R9, R10: 10k; R_10.16mm_CNC
R11: 680k; R_7.62mm_CNC
R12: 680k; R_10.16mm_CNC
R13, R15, R17: 47k; R_7.62mm_CNC
R14: 220k; R_7.62mm_CNC
R16, R23, R24: 100k; R_7.62mm_CNC
R18: 1M; R_7.62mm_CNC
R19, R20, R22: 100; R_10.16mm_CNC
R21: 47k; R_10.16mm_CNC
RV1: 1k; Potentiometer_Trim_CNC
RV2: 100k; Potentiometer_Trim_CNC
RV3, RV4, RV6: A1M; Potentiometer_PanelMount_CNC
RV5: B100k; Potentiometer_PanelMount_CNC
U1: TL074; DIP-14_CNC
U2: NA555P; DIP-8_CNC

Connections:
ENV: R7.2, R24.1, U1.1
GATE: J1.6, Q4.2 (B)
GND: C2.1, C3.1, D1.2 (A), J1.2, Q2.2 (B), Q3.1 (C), Q4.3 (E), Q5.3 (E), Q6.3 (E), R2.1, R12.2, U1.3 (+), U2.1 (GND)
IN: J1.5, R1.2
unnamed: C1.2, D1.1 (K), R16.2
unnamed: C3.2, D2.2 (A), D3.1 (K), D4.2 (A), U1.5 (+)
unnamed: D2.1 (K), RV3.2, RV3.3
unnamed: D3.2 (A), RV4.2, RV4.3
unnamed: D4.1 (K), RV6.2, RV6.3
unnamed: Q1.2 (B), R1.1, R2.2
unnamed: Q1.1 (C), R3.1, R9.2
unnamed: Q1.3 (E), Q2.3 (E), R5.2
unnamed: Q2.1 (C), R4.1, R10.2
unnamed: Q3.2 (B), R7.1, R8.1
unnamed: Q3.3 (E), R5.1, R6.2
unnamed: Q4.1 (C), R13.1, R14.2
unnamed: Q5.2 (B), R14.1
unnamed: C1.1, Q5.1 (C), R15.1, R18.2, R19.2, U2.4 (R)
unnamed: Q6.2 (B), R16.1
unnamed: Q6.1 (C), R17.1, U2.2 (TR)
unnamed: Q7.3 (D), RV5.1
unnamed: Q7.2 (G), R18.1
unnamed: Q7.1 (S), U2.7 (DIS)
unnamed: R3.2, RV1.1
unnamed: R4.2, RV1.3
unnamed: R8.2, RV2.2
unnamed: R19.1, RV3.1
unnamed: R20.1, RV4.1
unnamed: R21.2, RV5.3
unnamed: R22.1, RV6.1
unnamed: R23.1, R24.2, U1.2 (-)
unnamed: R23.2, U1.6 (-), U1.7, U2.6 (THR)
unnamed: R10.1, R12.1, U1.10 (+)
unnamed: R9.1, R11.2, U1.9 (-)
unnamed: RV5.2, U1.12 (+)
unnamed: R22.2, U1.13 (-), U1.14
unnamed: C2.2, U2.5 (CV)
unnamed: R20.2, U2.3 (Q)
OUT: J1.4, R11.1, U1.8
VCC: J1.3, R13.2, R15.2, R17.2, R21.1, RV1.2, RV2.1, U1.4 (V+), U2.8 (VCC)
VEE: J1.1, R6.1, RV2.3, U1.11 (V-)

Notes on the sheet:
Envalope
Envalope VCA
IC Power
Decay
INPUTS/OUTPUTS
Attack
Release
Sustain



Board: 2 copper layers, 50.8 x 177.8 mm, 47 parts (4 on the bottom side), 41 nets.

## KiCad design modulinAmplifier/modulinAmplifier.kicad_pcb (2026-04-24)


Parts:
C1, C2, C6: 100u; C_Radial_Polarized_P3.8mm_CNC
C3, C4: 1u; C_Axial_P5.00mm_CNC
C5: 10u; C_Axial_P5.00mm_CNC
C7: 33n; C_Axial_P5.00mm_CNC
C8: 47n; C_Axial_P5.00mm_CNC
C9: 220u; C_Radial_Polarized_P3.8mm_CNC
C10: 100n; C_Axial_P5.00mm_CNC
D1, D2: 1N4148; D_P7.62mm_CNC
J1: Screw_Terminal_01x04; TerminalBlock_1x4_CNC
J2: AudioJack3_SwitchTR; Jack_3.5mm_CUI_SJ1-3525N_Horizontal
J3: Screw_Terminal_01x02; TerminalBlock_1x2_CNC
R1: 1M; R_10.16mm_CNC
R2: 100; R_10.16mm_CNC
R3: 10k; R_7.62mm_CNC
R4: 10; R_10.16mm_CNC
RV1: 100k; Potentiometer_PanelMount_CNC
RV2: 100k; Potentiometer_Trim_CNC
U1: TL072; DIP-8_CNC
U2: LM386; DIP-8_CNC

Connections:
GND: C1.2, C2.1, C3.2, C4.1, C6.2, C10.1, D1.1 (K), D2.2 (A), J1.3, J2.S, J3.2, R4.1, RV1.1, RV2.3, U2.2 (-), U2.4 (GND)
IN: J1.1, U1.3 (+)
unnamed: C5.2, R1.1
unnamed: C7.1, R3.2
unnamed: C7.2, C8.2, C9.1, U2.5
unnamed: C8.1, R4.2
unnamed: D1.2 (A), D2.1 (K), RV1.2, U1.5 (+)
unnamed: J2.R, J2.RN
unnamed: J2.T, R2.2
unnamed: J2.TN, RV2.1
unnamed: C9.2, J3.1
unnamed: R1.2, RV1.3
unnamed: R3.1, U2.8 (GAIN)
unnamed: C5.1, U1.1, U1.2 (-)
unnamed: R2.1, U1.6 (-), U1.7
unnamed: RV2.2, U2.3 (+)
unnamed: C10.2, U2.7 (BYPASS)
VCC: C1.1, C3.1, C6.1, J1.4, U1.8 (V+), U2.6 (V+)
VEE: C2.2, C4.2, J1.2, U1.4 (V-)


Board: 2 copper layers, 76.2 x 50.8 mm, 23 parts (1 on the bottom side), 19 nets.

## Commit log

2025-05-07 Create Schematic
    [ADSR.kicad_sch, VCA.kicad_sch, VCF.kicad_sch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]
2025-05-12 Add power schematic
    [ADSR.kicad_sch, SynthPowerSupply.kicad_pcb, SynthPowerSupply.kicad_sch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]
2025-05-14 Create Power supply PCB
    [SynthPowerSupply-B_Cu.gbr, SynthPowerSupply-B_Mask.gbr, SynthPowerSupply-B_Paste.gbr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]
2025-06-05 Edit powersupply pcb
    [SynthPowerSupply.kicad_pcb]
2025-11-10 Start OCB design for parts
    [VCO.kicad_sch, modulinEnvelope.kicad_pcb, modulinEnvelope.kicad_sch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]
2025-11-13 Write out envelope circuit and make PCB, edit PSU
    [modulinEnvelope.kicad_pcb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]
2025-11-19 Finish VCO PCB
    [modulinPowerSupply.kicad_pcb, modulinVCO.kicad_pcb, modulinVCO.kicad_sch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]
2026-03-09 Finished up LFO PCB
    [modulinLFO.kicad_pcb, modulinLFO.kicad_sch, oscCore.kicad_sch]
2026-04-22 Add VCF ciruit and edit for JLCPCB
    [modulinEnvelope-B_Cu.gbr, modulinEnvelope-B_Mask.gbr, modulinEnvelope-B_Silkscreen.gbr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]
2026-04-24 Add STEP files
    [modulinAmplifier-B_Cu.gbr, modulinAmplifier-B_Mask.gbr, modulinAmplifier-B_Paste.gbr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]
2026-05-06 Add modulin BOM csv
    [modulinAmplifier.csv, modulinControl.csv, modulinControl.kicad_sch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]
2026-08-25 finish up modeling
    [Key3C.stl, Key3CSharp.stl, Key3D.stl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]
2026-08-26 Finish up CAD
    [modulinEnvelope.kicad_sch, modulinLFO.kicad_pcb, modulinLFO.kicad_sch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]
